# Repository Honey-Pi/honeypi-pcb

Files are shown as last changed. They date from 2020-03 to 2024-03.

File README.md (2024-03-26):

# HoneyPi-PCB Overview

Printed circuit boards (PCB) for the Raspberry Pi to connect various sensors to avoid the use of jumper cables and flying resistors :-).

Three variants are available (0.x, 2.x, 3.x):
## HoneyPi-PCB V0.1 [link](./PCB_V0.1) no further development or maintenance.

## HoneyPi-PCB V2.x [link](./PCB_V2.x) designed for Raspberry Zero, Zero 2. Read the manual first for Raspberry 3 and 4.  
## HoneyPi-PCB V3.x [link](./PCB_V3.x) designed for Raspberry 3, Raspberry 4 and the Zeros.
## Rasperry 5 is not yet supported.
--> HoneyPi-PCB V2.x and V3.x have a different range of functions.  
 
## Sensor extension board HX711 & DS18b20 for HoneyPi-PCB V2.x [link](./PCB_Sensor_Board_2.x_HX711_DS18b20)  

## Sensor extension board BME280/680 for HoneyPi-PCB V2.x [link](./PCB_Sensor_Board_2.x_BME280_680_ATH10_HDC1080)  
## I2C Extender (one set to extend the range) [link](./PCB_I2C_Extender)

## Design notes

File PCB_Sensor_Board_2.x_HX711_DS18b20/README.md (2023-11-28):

# HoneyPi-PCB Sensor Board HX711 and DS18b20

Extension board for the HoneyPi-PCB 2.x.   
Pitch lenght 2.0 mm for Grove plugs or similar.  
Pitch lenght 2.54 mm for (e.g.) terminal blocks as an alternative. 
New: Wago cage clamp block support

Designed to be mounted close to the load cell. To ensure that the analogue voltage signal is subject to the least interference.  
Shielded cable to the load cell and aluminium housing are designed for this purpose.  
1x HX711 (two different types)  
3x DS18b20 (cable/external) + 1x DS18b20 TO-92 (board)  

Feature list and bill of material is still on working. 

## V2.0x circuit diagram [link](./HoneyPI_Platine_2.05_Sensor_Plan.pdf)  
Check out this [blogpost](https://www.honey-pi.de/)  

Status: Under development.  
This version is currently being procured and tested.  
Please do not order these without having contacted us before.  
Thank you for your understanding!   

You can upload this [gerber file](./Sensor_Board_2.05_HX711_DS18b2.zip) to [this manufactory service](https://jlcpcb.com/quote) to get few PCBs. 10 pieces of this board cost about 7 € with delivery.  
(price date 2021)

### Pictures
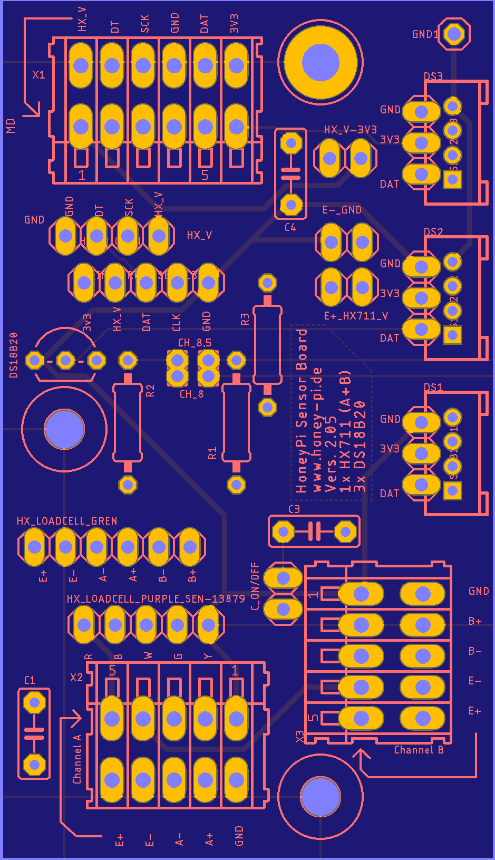
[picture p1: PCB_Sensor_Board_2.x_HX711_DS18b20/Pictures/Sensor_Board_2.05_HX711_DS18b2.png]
Board render picture


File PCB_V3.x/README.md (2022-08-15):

# HoneyPi-PCB 3.0x

Printed circuit board (PCB) for the Raspberry Pi 3 or 4 to connect various sensors.  
Pitch lenght 2.00 mm for Grove plugs or similar.  
Pitch lenght 2.54 mm for terminal blocks as an alternative. 
 
- Three differend possible power supplies possible.  
- 8x HX711 in combination with the PCB_HoneyPI_2.0 Sensor Board HX711_DS18b20  
- 8x DS18b20 + 1x DS18b20 (TO-92 onboard)  
- 8x I2C: BME680, BME280, PCF8591, OLED ...
- incl. interface for the WittyPi (90° connector)
- Space for momentary buttons, resistors, capacitors as well to connect the LED 

Designed for the Raspberry Pi 3 and 4 and also for the Raspberry Pi Zero WH / Zero 2 W   
Feature list and bill of material is still on working.  

## Circuit diagram [link](./HoneyPI_Platine_3.00_Schaltplan.pdf)
## Layout [link](./HoneyPI_Platine_3.00_layout.pdf)
Status: Tested.  

You can upload this [gerber file](./HoneyPI_Platine_3.00_2022-08-15.zip) to [this manufactory service](https://jlcpcb.com/quote) to get few PCBs. 5 pieces of this board cost me about 7 € with delivery. 

### Pictures
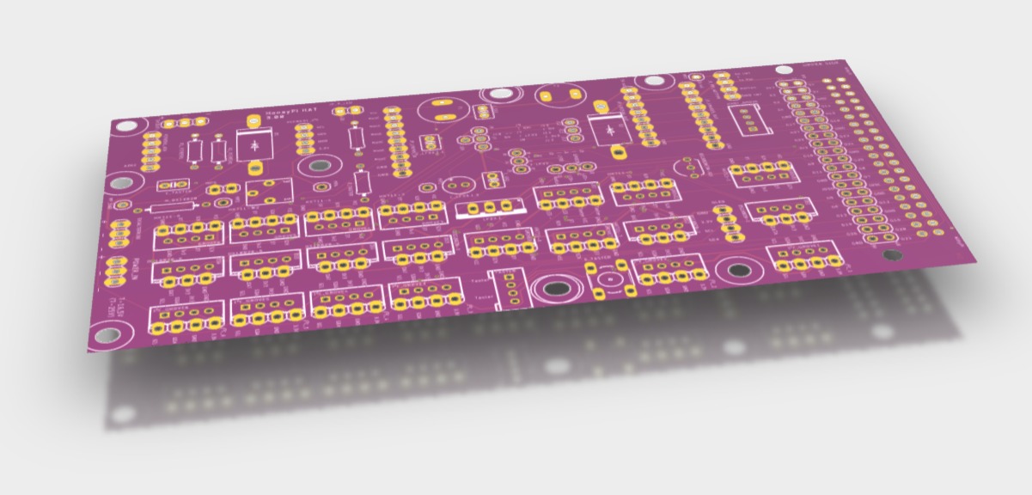
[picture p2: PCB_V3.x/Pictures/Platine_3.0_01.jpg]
Board render picture

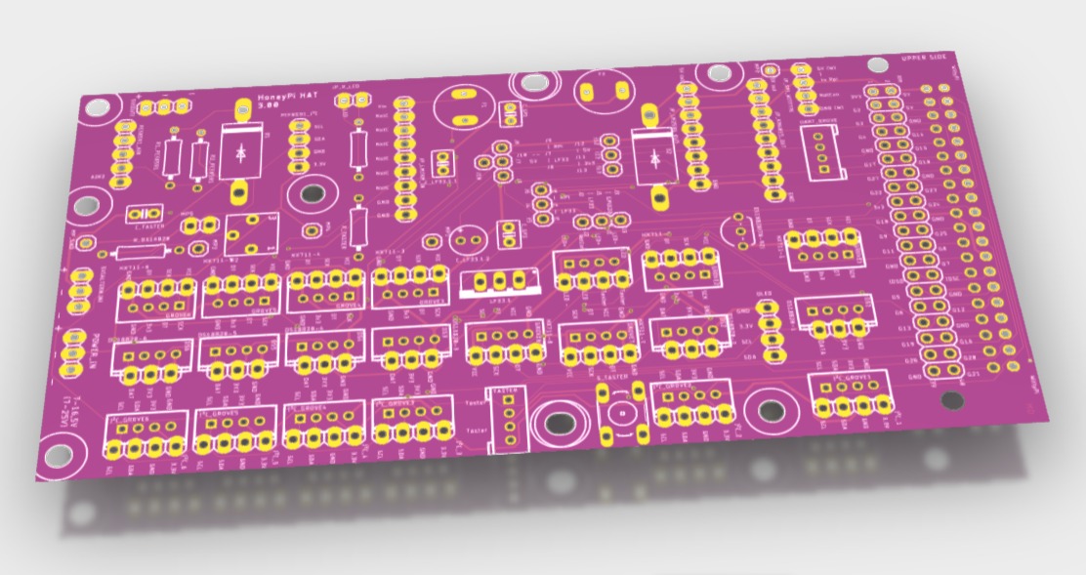
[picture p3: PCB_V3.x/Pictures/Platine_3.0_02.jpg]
Board render picture

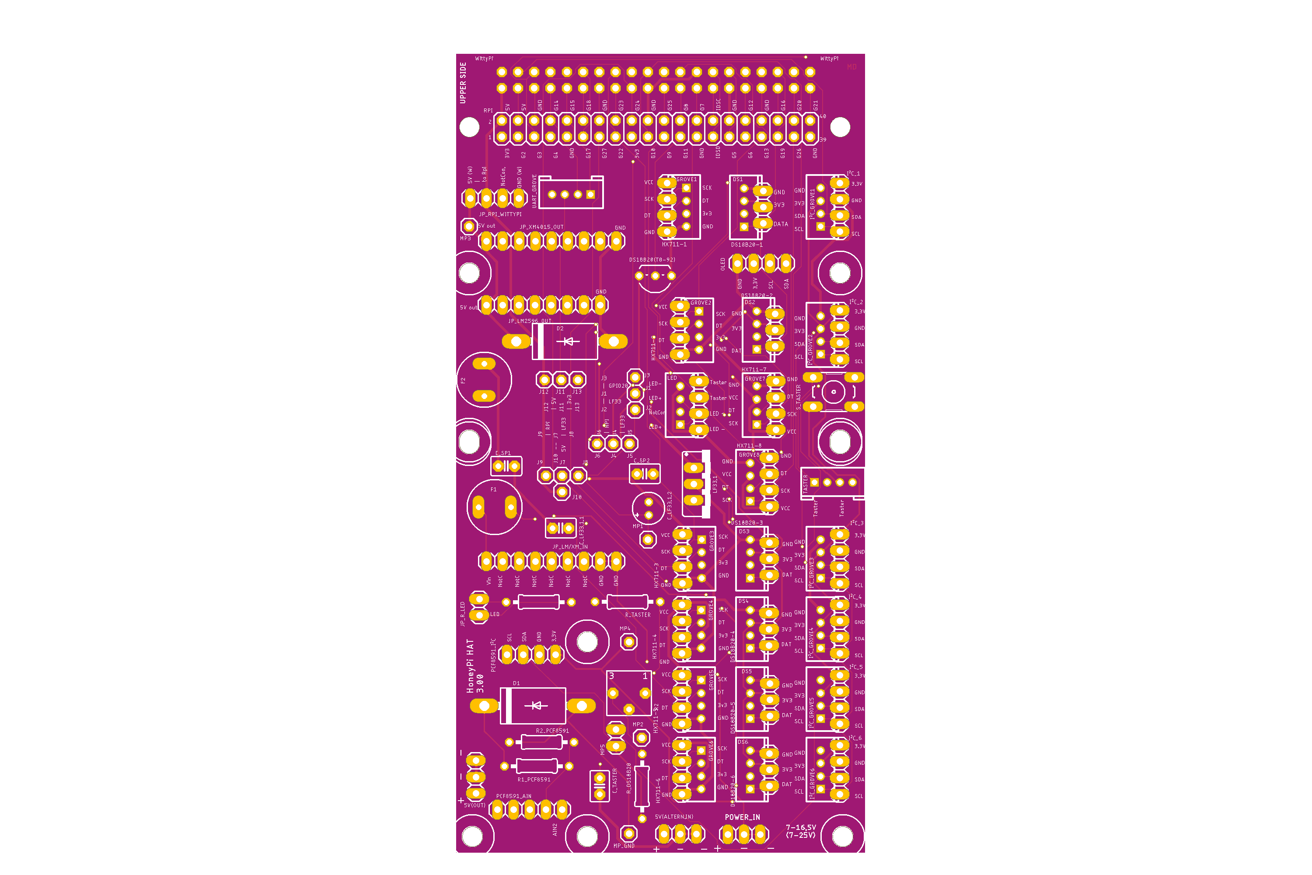
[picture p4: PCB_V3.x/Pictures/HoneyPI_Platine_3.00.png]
Board render picture


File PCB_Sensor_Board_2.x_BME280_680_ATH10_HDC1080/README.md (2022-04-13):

# HoneyPI-PCB Sensor Board 2.x BME280/BME680

Extension board for the HoneyPi-PCB 2.x.  
Pitch lenght 2.0 mm for Grove plugs or similar.  
Pitch lenght 2.54 mm for pins or...  
Designed to be mounted in a separate housing that allows humidity to be measured.  
1x BME680 or BME280 or 1x ATH10 or 1x HDC1080 or 1x sht31
--> We adapt these sensors because of the fixed i2c adresses. 

Feature list and bill of material is still on working.   

## V2.0x circuit diagram [link](./PCB_Sensor_Board_2.x_BME280_680_ATH10_HDC1080.pdf)
Check out this [blogpost](https://www.honey-pi.de/)

Status: Under development.  
This version is currently being procured and tested.  
Please do not order these without having contacted us before.  
Thank you for your understanding!  

You can upload this [gerber file](./PCB_Sensor_Board_2.x_BME280_680_ATH10_HDC1080.zip) to [this manufactory service](https://jlcpcb.com/quote) to get few PCBs. 10 pieces of this board cost about 7 € with delivery. 

### Pictures
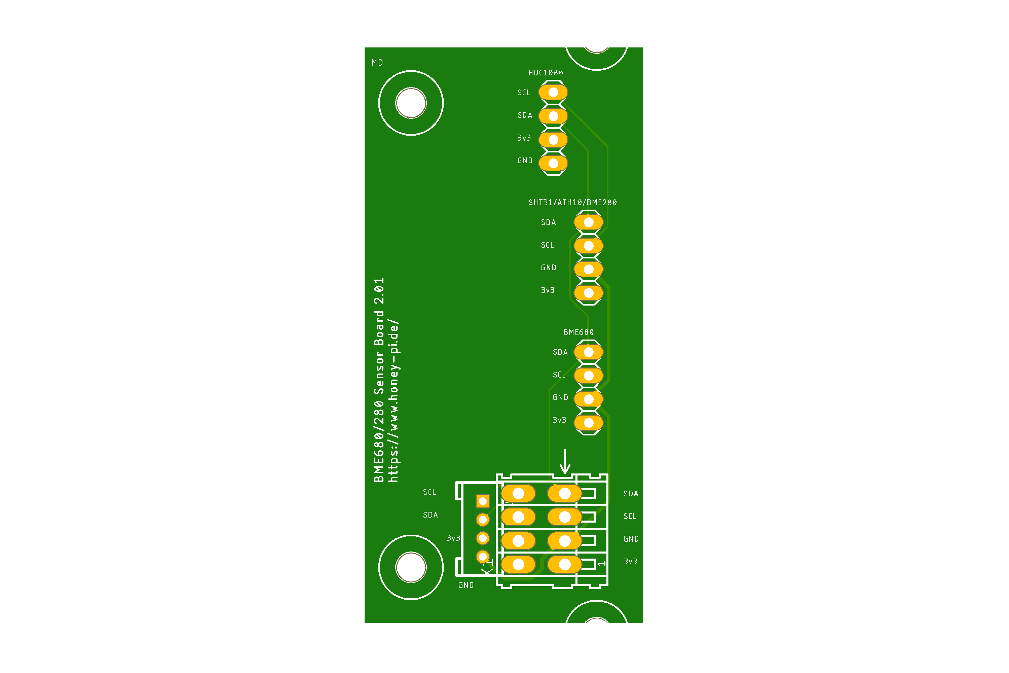
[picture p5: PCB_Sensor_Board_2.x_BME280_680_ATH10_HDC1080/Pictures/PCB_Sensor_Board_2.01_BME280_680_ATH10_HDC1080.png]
Board render picture


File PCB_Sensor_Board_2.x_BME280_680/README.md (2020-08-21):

# HoneyPI-PCB Sensor Board 2.x BME280/BME680

Extension board for the HoneyPi-PCB 2.x.  
Pitch lenght 2.0 mm for Grove plugs or similar.  
Pitch lenght 2.54 mm for pins or...  
Designed to be mounted in a separate housing that allows humidity to be measured.  
1x BME680 (or BME280)  
2x I²C   
...we are am thinking about a sunlight sensor or.

Feature list and bill of material is still on working.   

## V2.0 BETA circuit diagram [link](./HoneyPI_Platine_2.0_BME680_280_Sensor_Board_21-8-2020.pdf)
Check out this [blogpost](https://www.honey-pi.de/)

Status: Under development.  
This version is currently being procured and tested.  
Please do not order these without having contacted us before.  
Thank you for your understanding!  

You can upload this [gerber file](./HoneyPI_Platine_2.0_BME680_280_Sensor_Board_2020-08-21.zip) to [this manufactory service](https://jlcpcb.com/quote) to get few PCBs. 10 pieces of this board cost about 7 € with delivery. 

### Pictures
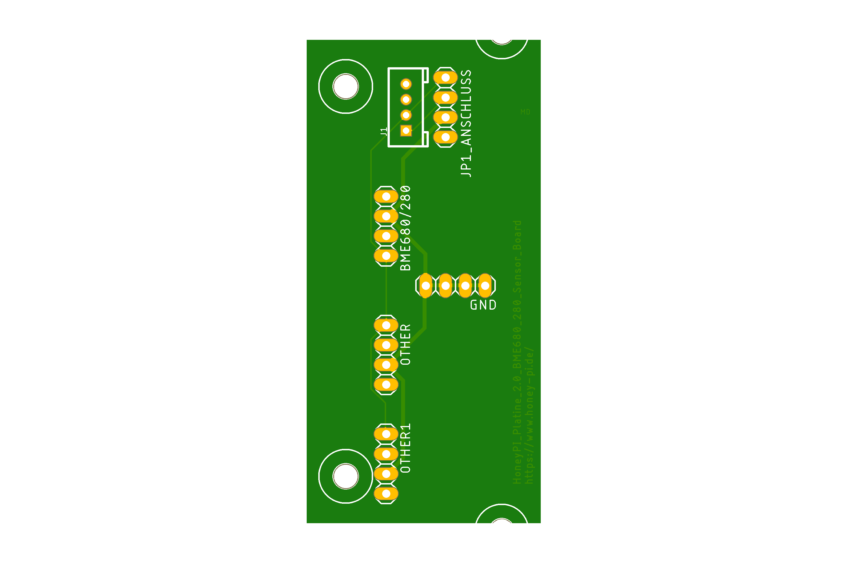
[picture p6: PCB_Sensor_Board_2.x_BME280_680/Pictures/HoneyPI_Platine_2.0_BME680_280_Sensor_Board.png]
Board render picture


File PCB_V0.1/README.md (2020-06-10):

# honeypi-pcb V0.1

Printed circuit board (PCB) for the Raspberry Pi to connect various sensors. To avoid the use of jumper cables.

## V0.1 [link](./PCB_V0.1)
Check out this [blogpost](https://www.honey-pi.de/teil-3-adapter-lk-fuer-grove-stecker/) about the grove connector board for the Raspberry Zero.
You can upload the [gerber file](./Grove%20Base%20HAT%20For%20Raspberry%20Pi%20Zero_2019-01-13.zip) to [this manufactory service](https://jlcpcb.com/quote). 10 pieces of this board cost about 7 € with delivery. 

### Pictures
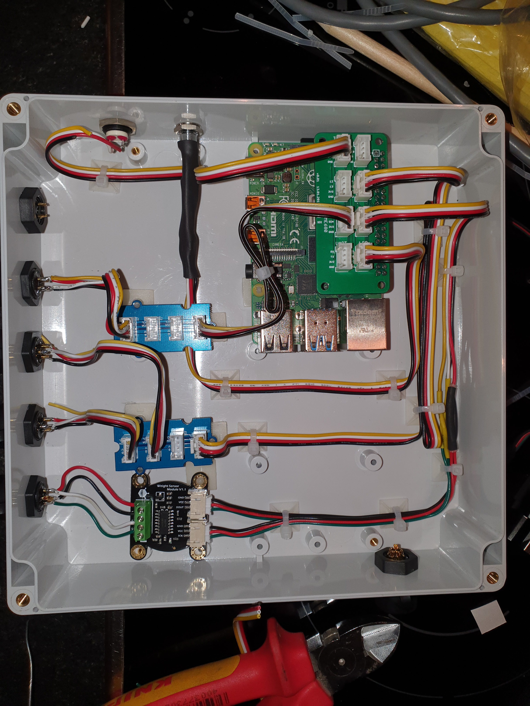
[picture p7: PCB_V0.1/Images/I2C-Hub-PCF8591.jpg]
RPi 4 with Board

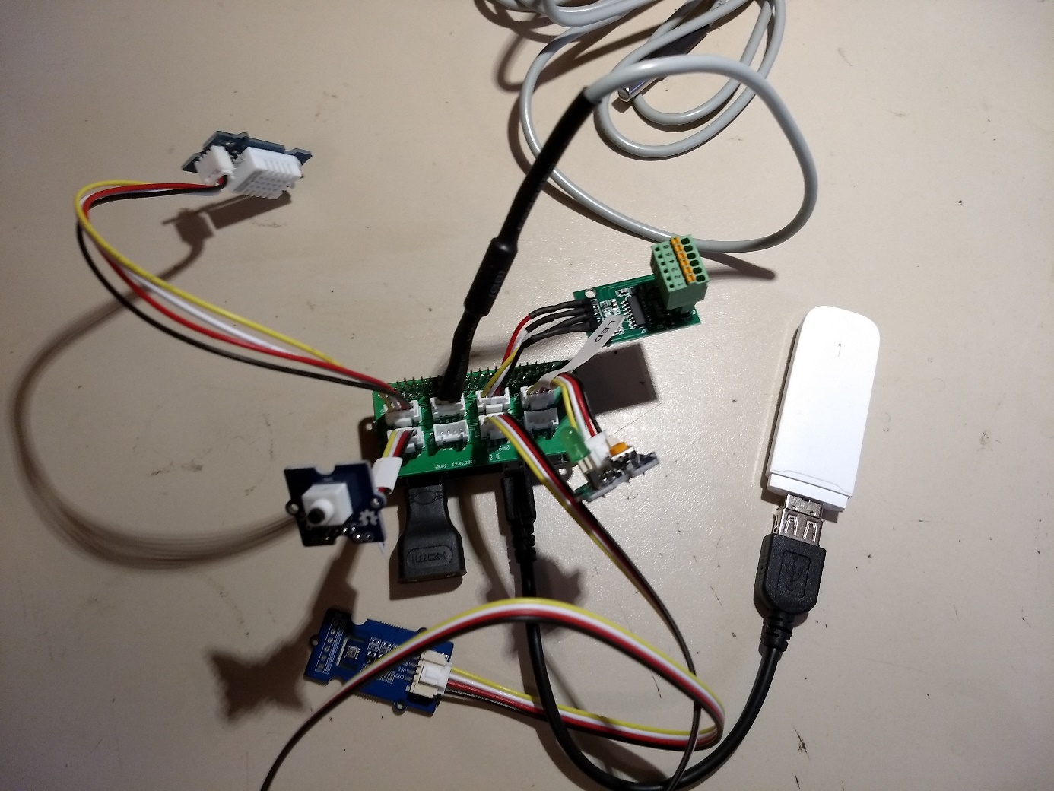
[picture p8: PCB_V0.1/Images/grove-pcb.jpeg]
RPi Zero with Board

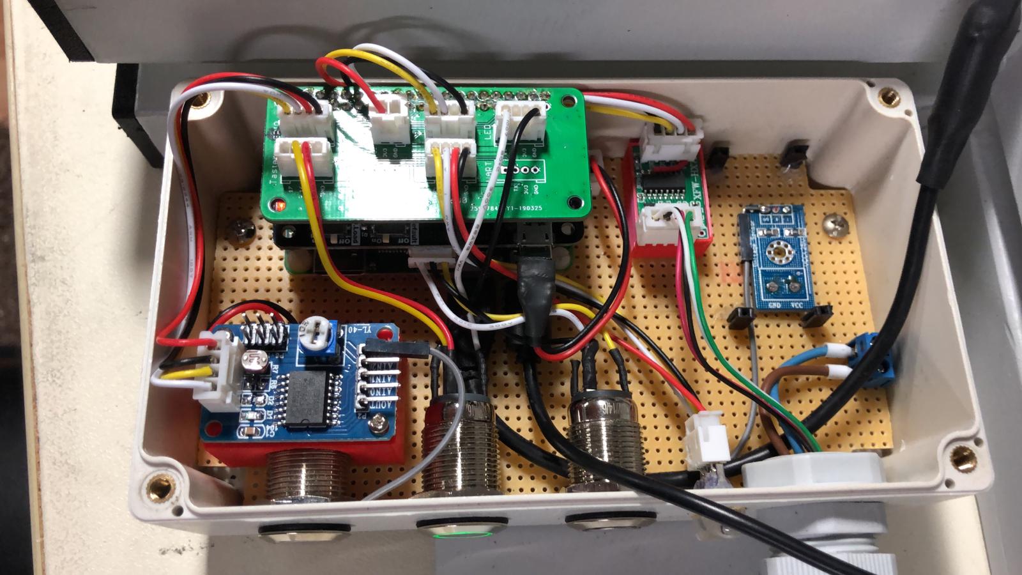
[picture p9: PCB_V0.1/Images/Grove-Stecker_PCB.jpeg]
RPi Zero WittyPi + PCB Board


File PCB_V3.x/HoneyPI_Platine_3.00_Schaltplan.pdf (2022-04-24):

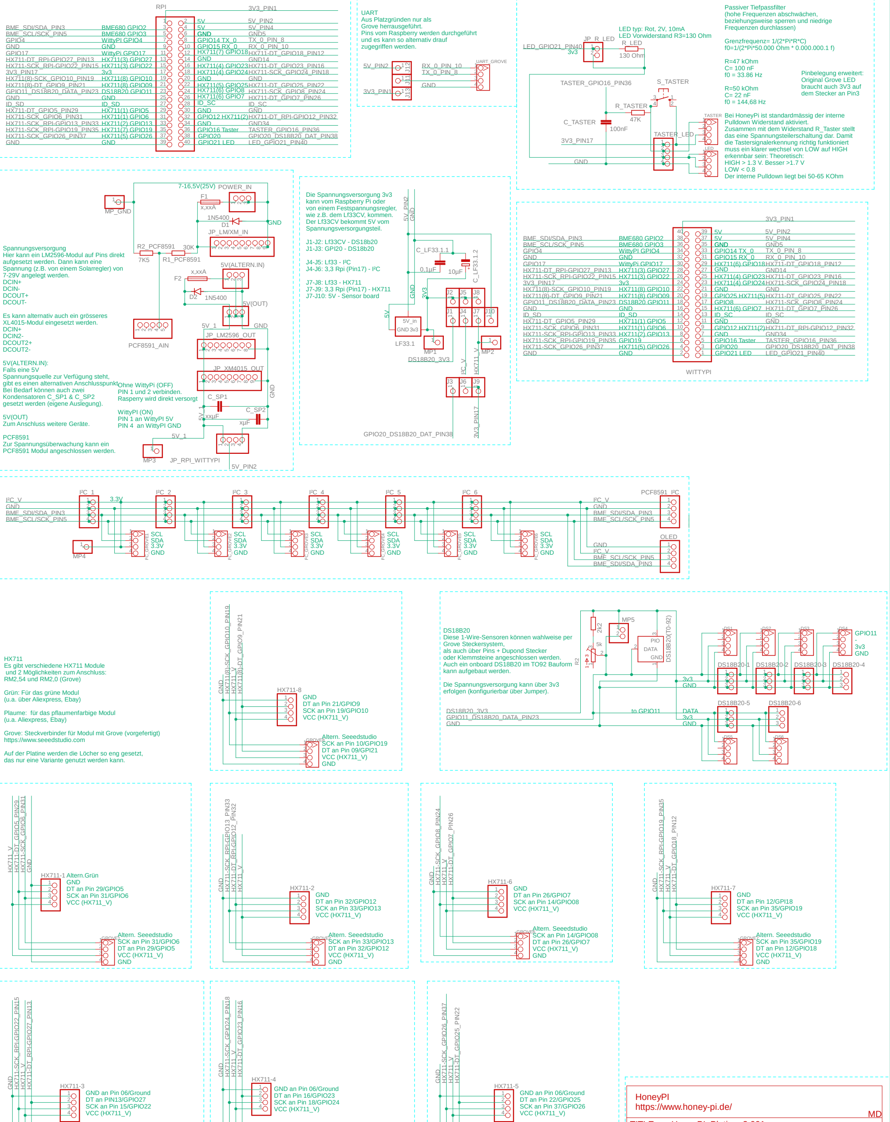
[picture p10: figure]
SpiceOrder 2; SpiceOrder 1; SpiceOrder 1 xxµF; xµF; 130 Ohm 2k2; x,xxA; RPI; 4 TASTER_LED; R_LED; 3 POWER_IN; PIO; GND; DATA 2; DS¹⁸B²⁰⁽T0⁻92⁾; 3 5V(OUT); R2_PCF8591; R1_PCF8591; LED; 4TASTER; C_TASTER; R_TASTER; 4GROVE1; 4GROVE2; 4 I²C_GROVE¹; HX711(4) GPIO24; TX_0_PIN_8 2; 4UART_GROVE; 4 PCF8591_I²C; 4 2 S_TASTER; I²C_2; I²C_1; JP_RPI_WITTYPI; 5V(ALTERN.IN); 5V_in GND 3v3; JP_R_LED; JP_XM4015_OUT; JP_LM2596_OUT; 4 OLED; 4 I²C_GROVE²; 4GROVE6; I²C_3; 4 I²C_GROVE³; I²C_4; 4 I²C_GROVE⁴; I²C_5; 4 I²C_GROVE⁵; I²C_6; 4 I²C_GROVE⁶; 40 39 WITTYPI; 4GROVE7; 4GROVE8; 1 MP_GND; HX711(4) GPIO23; 5 PCF8591_AIN; HX711-DT_GPIO5_PIN29; BME_SCL/SCK_PIN5; BME_SCL/SCK_PIN5 HX⁷¹¹_V; HX⁷¹¹_V HX⁷¹¹_V HX⁷¹¹_V; HX⁷¹¹_V; HX⁷¹¹_V HX⁷¹¹_V; HX711-DT_RPI-GPIO12_PIN32; LED_GPIO21_PIN40; TASTER_GPIO16_PIN36; TASTER_GPIO16_PIN36 HX⁷¹¹⁻SCK_RPI-GPIO¹³_PIN³³; HX711-SCK_RPI-GPIO13_PIN33; HX711-DT_RPI-GPIO27_PIN13 HX⁷¹¹⁻SCK_RPI-GPIO²²_PIN¹⁵; HX711-SCK_RPI-GPIO22_PIN15; HX711-DT_GPIO23_PIN16 HX711-SCK_GPIO24_PIN18; HX711-SCK_GPIO6_PIN31; HX711-DT_GPIO25_PIN22 HX⁷¹¹⁻SCK_GPIO²⁶_PIN³⁷; HX711-SCK_GPIO26_PIN37; TX_0_PIN_8; RX_0_PIN_10; BME_SDI/SDA_PIN3; 3V3_PIN17; 3V3_PIN17 3V³_PIN¹⁷; 3V3_PIN1; I²C_V; I²C_V I²C_V ⁵V_PIN²; 5V_PIN2; GPIO11_DS18B20_DATA_PIN23; GPIO11_DS18B20_DATA_PIN23 ⁵V_1; HX711-SCK_GPIO8_PIN24; HX711-SCK_GPIO8_PIN24 HX⁷¹¹⁻SCK_GPIO⁸_PIN²⁴ HX711-DT_GPIO7_PIN26; HX711(8)-SCK_GPIO10_PIN19; HX711(8)-SCK_GPIO10_PIN19 HX⁷¹¹⁽⁸⁾⁻SCK_GPIO¹⁰_PIN¹⁹; HX711-DT_GPIO18_PIN12; GPIO20_DS18B20_DAT_PIN38; GPIO20_DS18B20_DAT_PIN38 GND GND; GND GND; GND GND GND; GND GND GND GND GND; GND GND GND GND; GPIO4; GPIO4 GPIO17; GPIO17; 5V_PIN4; GND5; GND14; GND34; HX711-SCK_RPI-GPIO19_PIN35; HX⁷¹¹⁻SCK_RPI-GPIO¹⁹_PIN³⁵; HX711(8)-DT_GPIO9_PIN21; HoneyPI; https://www.honey-pi.de/; 3v3 DATA GND; 3v3 GND; HX711(7) GPIO18; Altern.Grün GND; BME680 GPIO2 BME680 GPIO3 WittyPI GPIO4; WittyPi GPIO17 GND; HX711(1) GPIO6; 5VGPIO12 HX711(2); GPIO11; -3v3 GND; to GPIO11; HX711(5) GPIO25; HX711(5) GPIO26; GND GPIO15 RX_0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

# HX711-DT_GPIO5_PIN29 HX⁷¹¹⁻DT_GPIO⁵_PIN²⁹

# HX711-DT_RPI-GPIO12_PIN32 HX⁷¹¹⁻DT_RPI-GPIO¹²_PIN³²

# HX711-DT_RPI-GPIO27_PIN13 HX⁷¹¹⁻DT_RPI-GPIO²⁷_PIN¹³

# HX711-DT_GPIO23_PIN16 HX⁷¹¹⁻DT_GPIO²³_PIN¹⁶

# HX711-SCK_GPIO24_PIN18 HX⁷¹¹⁻SCK_GPIO²⁴_PIN¹⁸

# HX711-SCK_GPIO6_PIN31 HX⁷¹¹⁻SCK_GPIO⁶_PIN³¹

HX711-DT_GPIO25_PIN22 | HX⁷¹¹⁻DT_GPIO²⁵_PIN²²
HX711-DT_GPIO7_PIN26 | HX⁷¹¹⁻DT_GPIO⁷_PIN²⁶

# HX711-DT_GPIO18_PIN12 HX⁷¹¹⁻DT_GPIO¹⁸_PIN¹²

# HX711(8)-DT_GPIO9_PIN21 HX⁷¹¹⁽⁸⁾⁻DT_GPIO⁹_PIN²¹

DT an Pin 29/GPIO5 SCK an Pin 31/GPIO6 VCC (HX711_V)

HX711(8) GPIO09 DS18B20 GPIO11 HX711(1) GPIO5

HX711(2) GPIO13 GND GND | GND GPIO16 Taster GPIO21 LED GND GND GND GND
Altern. Seeedstudio SCK an Pin 31/GPIO6 DT an Pin 29/GPIO5 VCC (HX711_V) GND | GND
DT an Pin 32/GPIO12 SCK an Pin 33/GPIO13 VCC (HX711_V) Altern. Seeedstudio SCK an Pin 33/GPIO13 DT an Pin 32/GPIO12 VCC (HX711_V) GND GND an Pin 06/Ground DT an PIN13/GPIO27 SCK an Pin 15/GPIO22 VCC (HX711_V) Altern. Seeedstudio SCK an Pin 15/GPIO22 DT an PIN13/GPIO27 VCC (HX711_V) GND | GND an Pin 06/Ground DT an Pin 16/GPIO23 SCK an Pin 18/GPIO24 VCC (HX711_V) | Altern. Seeedstudio SCK an Pin 18/GPIO24 DT an Pin 16/GPIO23 VCC (HX711_V) GND | GND an Pin 06/Ground DT an Pin 22/GPIO25 SCK an Pin 37/GPIO26 VCC (HX711_V) Altern. Seeedstudio SCK an Pin 37/GPIO26 DT an Pin 22/GPIO25 VCC (HX711_V) GND

Grove: Steckverbinder für Modul mit Grove (vorgefertigt)

Auf der Platine werden die Löcher so eng gesetzt,

das nur eine Variante genutzt werden kann. | DS18B20 Diese 1-Wire-Sensoren können wahlweise per

oder Klemmsteine angeschlossen werden. Auch ein onboard DS18B20 im TO92 Bauform

Pins vom Raspberry werden durchgeführt und es kann so alternativ drauf zugegriffen werden.

Spannungsversorgung Hier kann ein LM2596-Modul auf Pins direkt aufgesetzt werden. Dann kann eine

Spannung (z.B. von einem Solarregler) von 7-29V angelegt werden. DCIN+ DCIN- DCOUT+ DCOUT- Es kann alternativ auch ein grösseres

XL4015-Modul eingesetzt werden. DCIN+ DCIN2- DCOUT2+ DCOUT2- 5V(ALTERN.IN): Falls eine 5V

gibt es einen alternativen Anschlusspunkt. Bei Bedarf können auch zwei Kondensatoren C_SP1 & C_SP2

5V(OUT) Zum Anschluss weitere Geräte. PCF8591 Zur Spannungsüberwachung kann ein

wie z.B. dem Lf33CV, kommen. Der Lf33CV bekommt 5V vom f0=1/(2*Pi*50.000 Ohm * 0.000.000.1 f) R=47 kOhm C= 100 nF

Bei HoneyPi ist standardmässig der interne Pulldown Widerstand aktiviert. Zusammen mit dem Widerstand R_Taster stellt

die Tastersignalerkennung richtig funktioniert muss ein klarer wechsel von LOW auf HIGH erkennbar sein: Theoretisch: HIGH > 1.3 V. Besser >1.7 V

LOW < 0.8 Der interne Pulldown liegt bei 50-65 KOhm

A

B

C

D

E

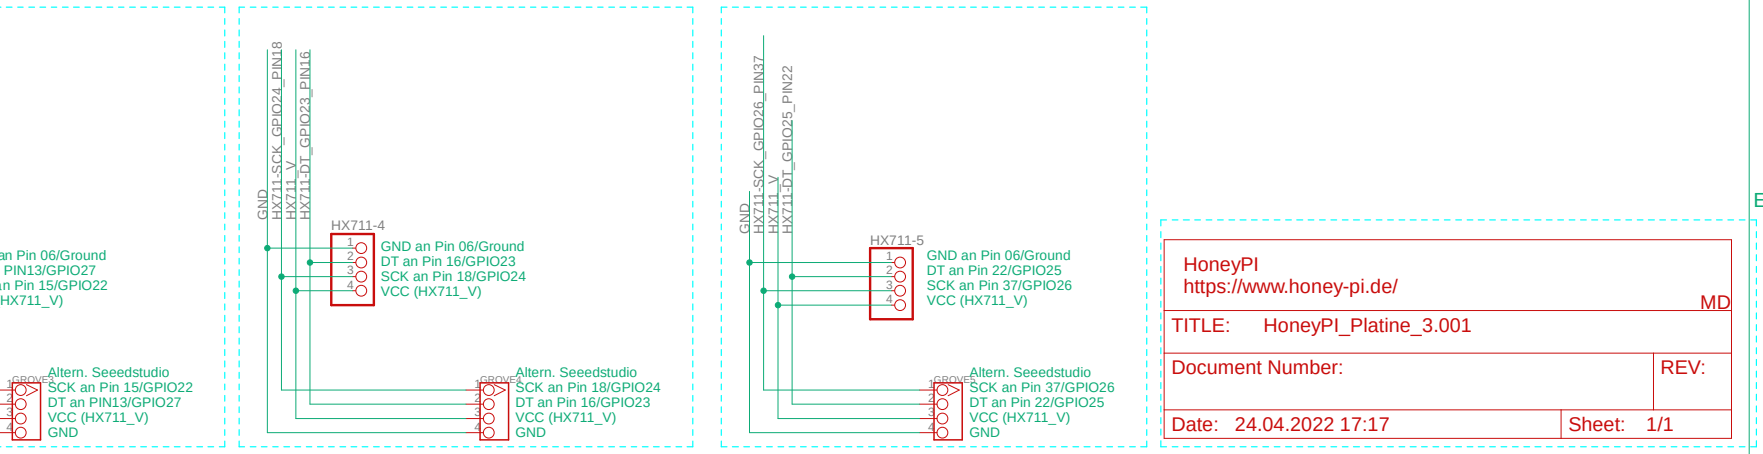
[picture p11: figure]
4GROVE3; 4GROVE4; 4GROVE5; Date:; Sheet:; REV:; TITLE:; Document Number:; HoneyPI_Platine_3.001

1 | 2 | 3 | 4 | 5 | 6 | 7 | 8

A

B

C

D

E

1 | 2 | 3 | 4 | 5 | 6 | 7 | 8

Ohne WittyPi (OFF) PIN 1 und 2 verbinden. Rasperry wird direkt versorgt

DT an Pin 26/GPIO7 SCK an Pin 14/GPIO08 VCC (HX711_V) Altern. Seeedstudio SCK an Pin 14/GPIO08 DT an Pin 26/GPIO7 VCC (HX711_V) GND

5VHX711(6) GPIO18 BME680 GPIO2 BME680 GPIO3 WittyPI GPIO4

HX711(8) GPIO09 DS18B20 GPIO11 HX711(1) GPIO5

HX711(2) GPIO13 GND | GND GPIO16 Taster GPIO21 LED GND GND GND GND

DT an Pin 12/GPI18 SCK an Pin 35/GPIO19 VCC (HX711_V) Altern. Seeedstudio SCK an Pin 35/GPIO19 DT an Pin 12/GPIO18 VCC (HX711_V) GND

DT an Pin 21/GPIO9 SCK an Pin 19/GPIO10 VCC (HX711_V) Altern. Seeedstudio SCK an Pin 10/GPIO19 DT an Pin 09/GPI21 VCC (HX711_V) GND

Original Grove LED braucht auch 3V3 auf dem Stecker an Pin3 HX711(8) GPIO10 GND

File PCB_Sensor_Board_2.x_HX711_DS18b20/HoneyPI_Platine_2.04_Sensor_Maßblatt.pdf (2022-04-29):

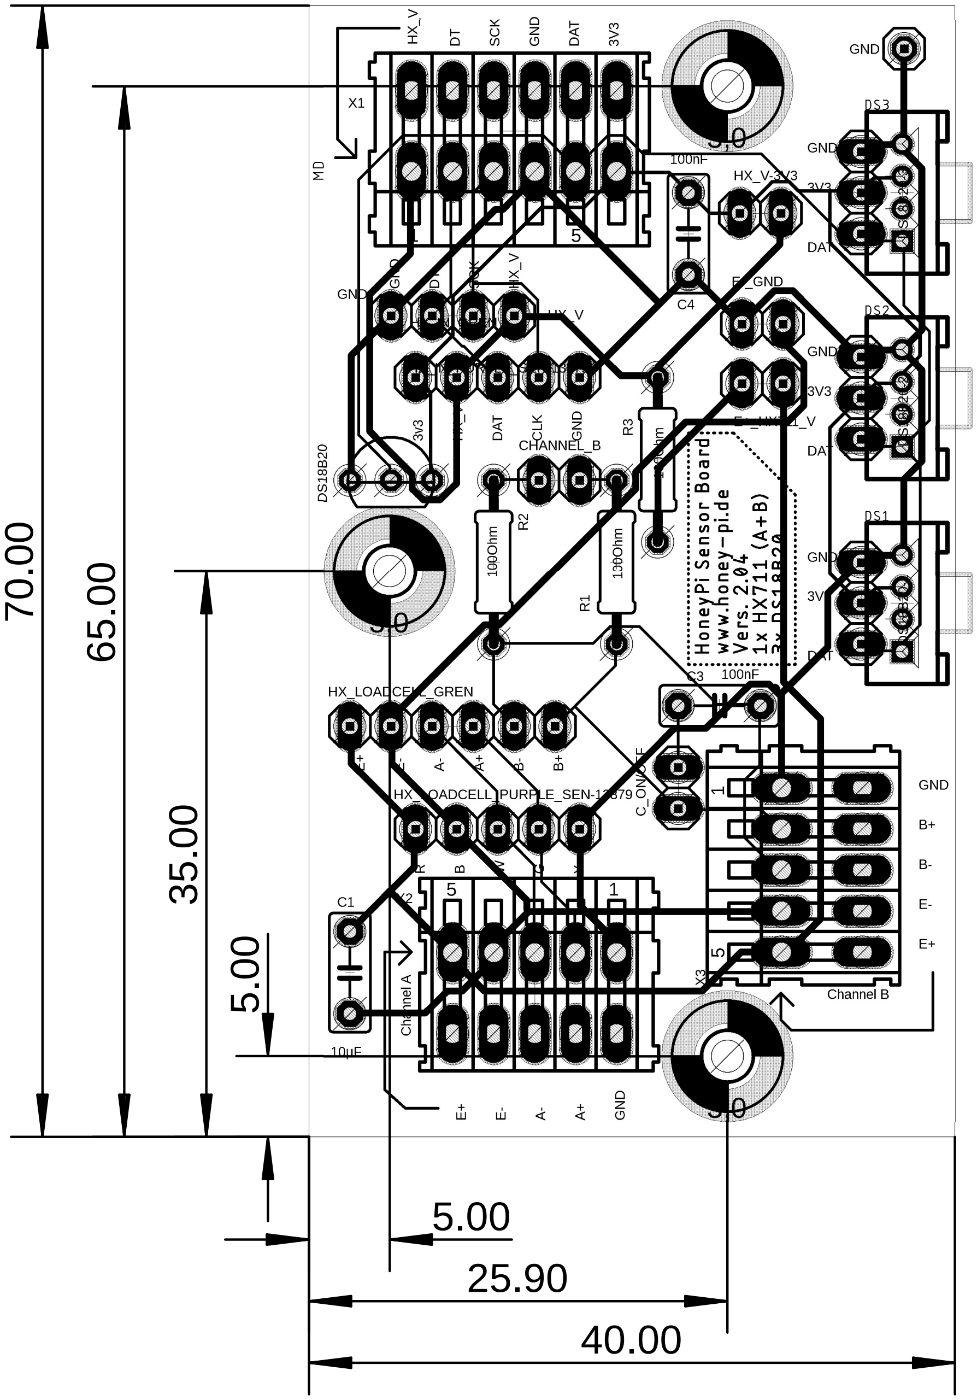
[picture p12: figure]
25.90 DS¹⁸B²⁰

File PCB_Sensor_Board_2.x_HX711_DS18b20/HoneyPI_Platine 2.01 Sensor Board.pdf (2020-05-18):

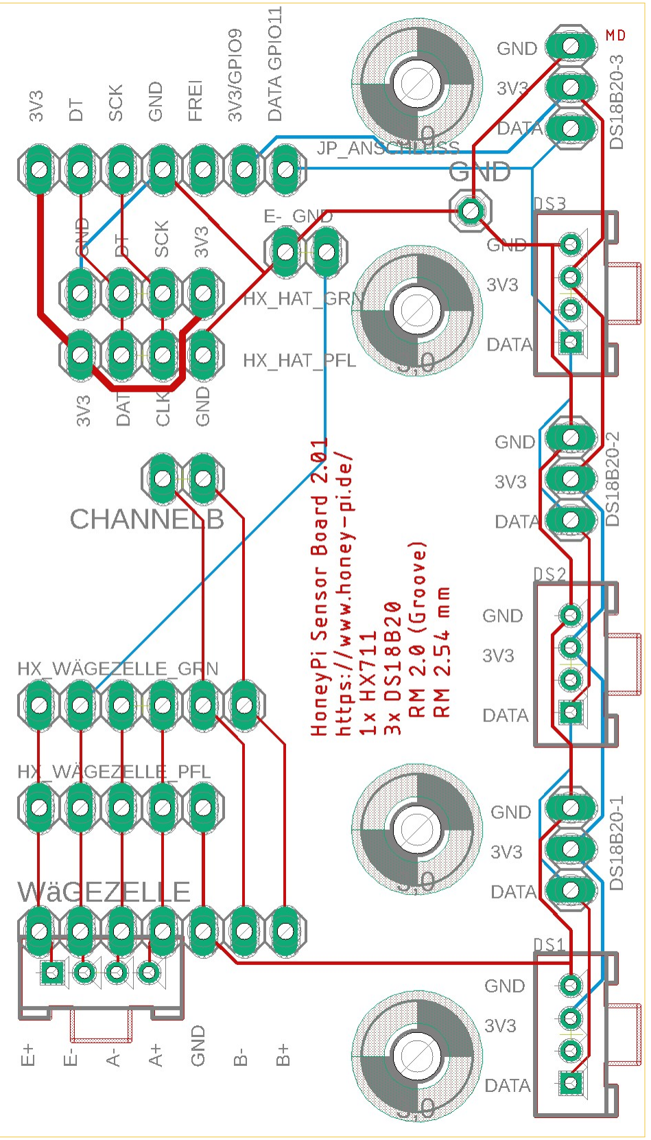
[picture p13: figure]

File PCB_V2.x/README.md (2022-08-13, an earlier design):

# HoneyPi-PCB 2.0x

Printed circuit board (PCB) for the Raspberry Pi ZERO to connect various sensors.  
Pitch lenght 2.x mm for Grove plugs or similar.  
Pitch lenght 2.54 mm for terminal blocks as an alternative. 
 
- Three differend possible power supplies possible.  

- 5x HX711...  

- 8x DS18b20 + 1x DS18b20 (TO-92 onboard)  

- 2x BME680 / BME280 

- 1x I²C interface (instead of second BME)

- 1x PCF8591

- incl. interface for the WittyPi / Timer Board

Designed for the Raspian Zero and NOT for Raspian Pi 1 to 4  
Feature list and bill of material is still on working.  
## You can find some helpfull instructions (only in German at the moment ) [here](./Bienenwaage_Platine_2.x_D2.07.pdf)

## V2.0x circuit diagram [link](./Schaltplan_2.021-13-8-2022.pdf)
Check out this [blogpost](https://honey-pi.de/neue-platine-v2-fuer-raspberry-zero/) for the Raspberry Zero.

Status: Tested, working.  
This version has been tested and found to be good and released.

You can upload this [gerber file](./HoneyPI_Platine_2.021_2022-08-13.zip) to [this manufactory service](https://jlcpcb.com/quote) to get few PCBs. 5 pieces of this board cost me about 7 € with delivery. 

### Pictures
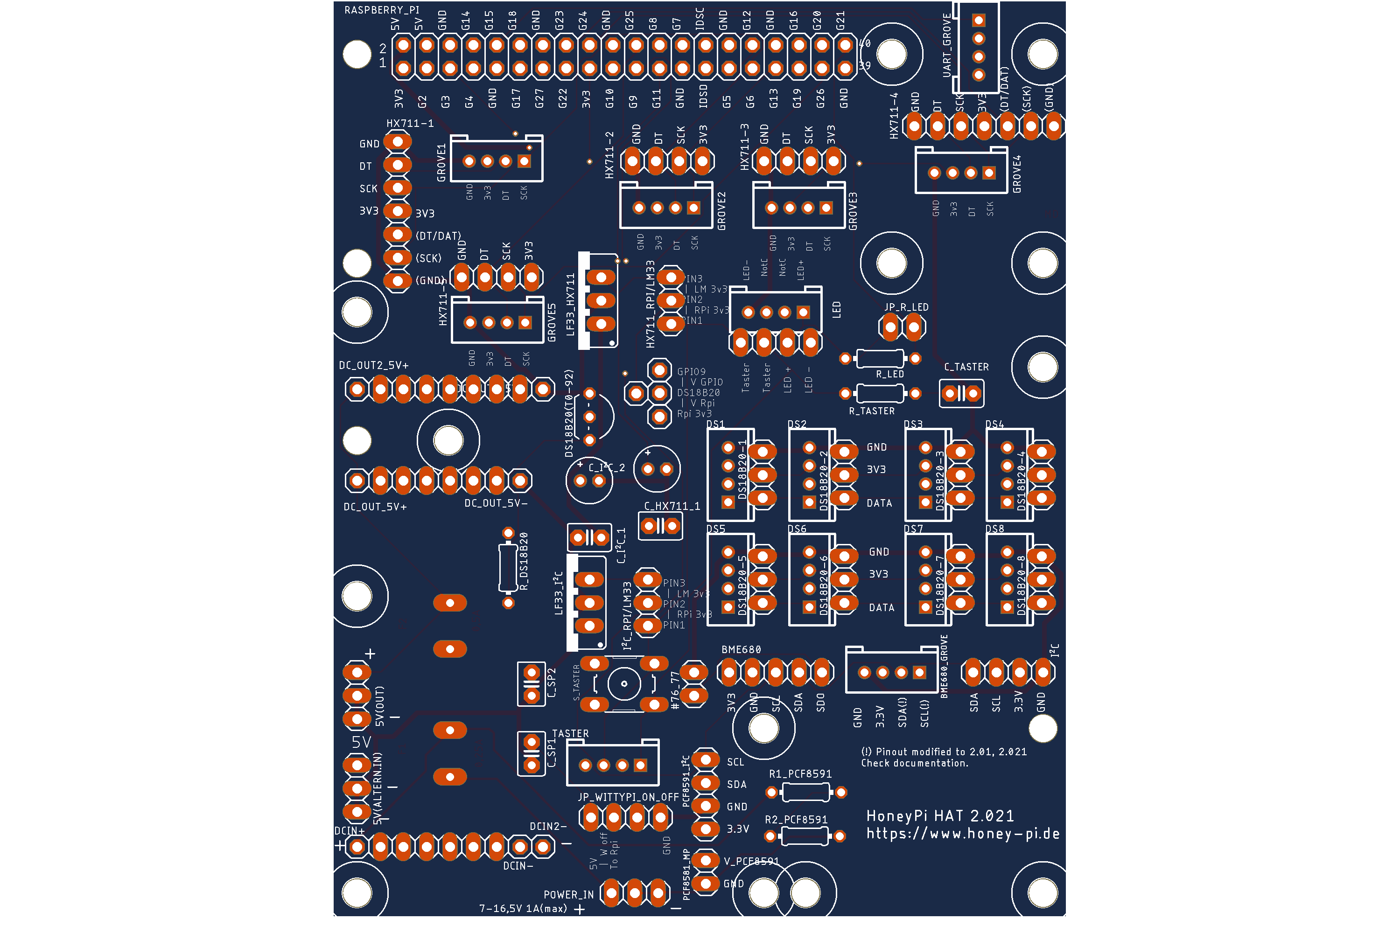
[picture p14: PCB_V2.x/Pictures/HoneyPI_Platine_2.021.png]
Board render picture


Users of the board version 2.01: Please use the schematic 2.01.1 [link](./OLD/Schaltplan_2.01.1-21.01.2021.pdf)

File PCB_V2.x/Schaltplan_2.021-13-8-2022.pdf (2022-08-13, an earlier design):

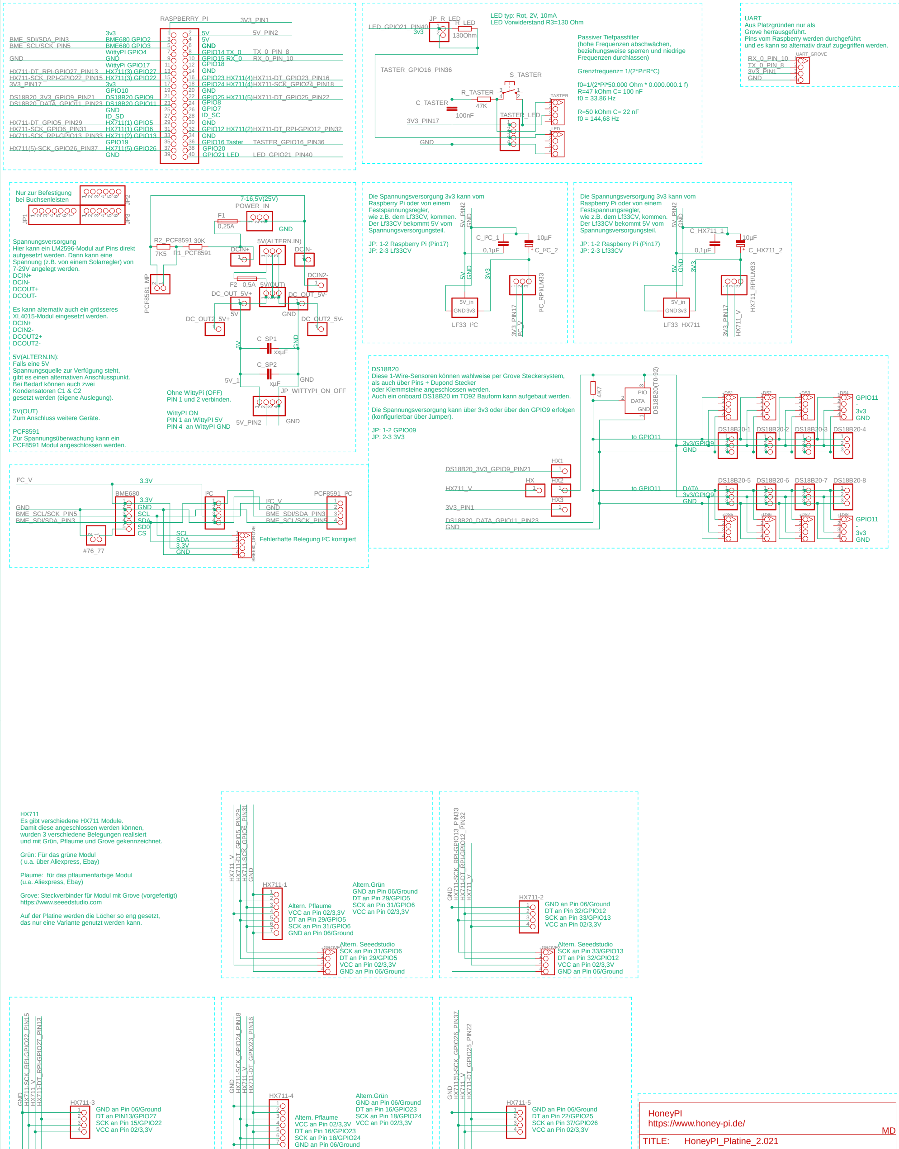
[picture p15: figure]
xxµF; xµF; 130Ohm; GND; RASPBERRY_PI; 4 TASTER_LED; R_LED; 1 DCIN+; 1 DCIN- 1 DC_OUT_5V+; 1 DC_OUT_5V- ¹; 3 POWER_IN; PIO; DATA 2; DS¹⁸B²⁰⁽T0⁻92⁾; 5V(OUT); R2_PCF8591; R1_PCF8591; LED; 4TASTER; C_TASTER; R_TASTER; 4GROVE1; 4GROVE2; 4 BME⁶⁸⁰_GROVE; 4UART_GROVE; 4 PCF8591_I²C; 3 I²C_RPI/LM33; C_I²C_1; 1 DC_OUT2_5V+; 1 DCIN2- 1 DC_OUT2_5V-; 4 2 S_TASTER; 1 PCF8581_MP; I²C; 5 BME680; 3 HX711_RPI/LM33; JP_WITTYPI_ON_OFF; 5V(ALTERN.IN); 5V_in GND 3v3; LF33_I²C; 5V_in GND3v3; C_I²C_2; JP_R_LED; BME_SCL/SCK_PIN5; BME_SCL/SCK_PIN5 HX⁷¹¹_V; HX⁷¹¹_V; HX⁷¹¹_V HX⁷¹¹_V; DS18B20_3V3_GPIO9_PIN21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

1
2
3

4GROVE3

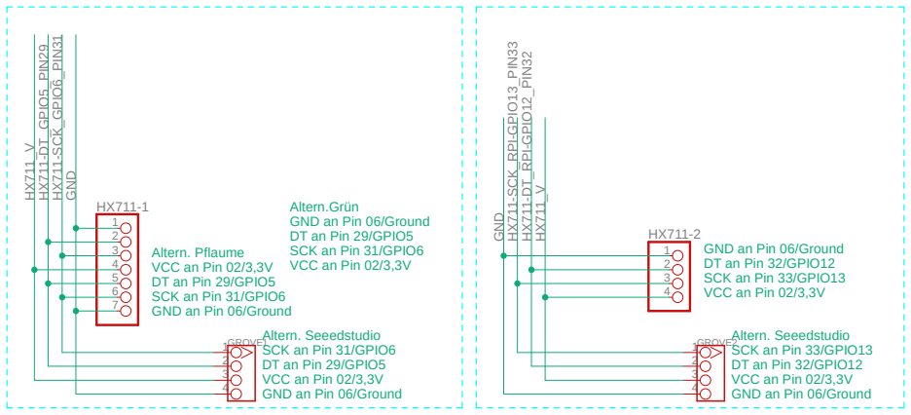
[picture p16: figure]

1
2
3
4GROVE4 | 1
2
3

4GROVE5

HX711-DT_GPIO5_PIN29 | HX⁷¹¹⁻DT_GPIO⁵_PIN²⁹
HX711-DT_RPI-GPIO12_PIN32 | HX⁷¹¹⁻DT_RPI-GPIO¹²_PIN³²

# TASTER_GPIO16_PIN36 HX⁷¹¹⁻SCK_RPI-GPIO¹³_PIN³³

HX711-DT_RPI-GPIO27_PIN13 HX⁷¹¹⁻SCK_RPI-GPIO²²_PIN¹⁵ | HX⁷¹¹⁻DT_RPI-GPIO²⁷_PIN¹³
HX711-SCK_RPI-GPIO22_PIN15 | HX711-DT_GPIO23_PIN16 HX⁷¹¹⁻DT_GPIO²³_PIN¹⁶

# HX711-SCK_GPIO24_PIN18 HX⁷¹¹⁻SCK_GPIO²⁴_PIN¹⁸

HX711-SCK_GPIO6_PIN31 | HX⁷¹¹⁻SCK_GPIO⁶_PIN³¹
HX711-DT_GPIO25_PIN22 | HX⁷¹¹⁽⁵⁾⁻SCK_GPIO²⁶_PIN³⁷ | HX⁷¹¹⁻DT_GPIO²⁵_PIN²²
Date: | Sheet:

## REV:

## Document Number:

12.08.2022 15:54 | 1/1

Altern. Pflaume VCC an Pin 02/3,3V DT an Pin 29/GPIO5 SCK an Pin 31/GPIO6 GND an Pin 06/Ground

Altern.Grün GND an Pin 06/Ground DT an Pin 29/GPIO5 SCK an Pin 31/GPIO6 VCC an Pin 02/3,3V

DS18B20 GPIO9 DS18B20 GPIO11 HX711(1) GPIO5

HX711(2) GPIO13 GND GND | GND GPIO16 Taster GPIO21 LED GND GND GND GND
Altern. Seeedstudio SCK an Pin 31/GPIO6 DT an Pin 29/GPIO5 VCC an Pin 02/3,3V GND an Pin 06/Ground | GND an Pin 06/Ground DT an Pin 32/GPIO12 SCK an Pin 33/GPIO13 VCC an Pin 02/3,3V

Altern. Seeedstudio SCK an Pin 33/GPIO13 DT an Pin 32/GPIO12 VCC an Pin 02/3,3V GND an Pin 06/Ground GND an Pin 06/Ground DT an PIN13/GPIO27 SCK an Pin 15/GPIO22 VCC an Pin 02/3,3V

Altern. Seeedstudio SCK an Pin 15/GPIO22 DT an PIN13/GPIO27 VCC an Pin 02/3,3V GND an Pin 06/Ground | Altern. Pflaume VCC an Pin 02/3,3V DT an Pin 16/GPIO23 SCK an Pin 18/GPIO24 GND an Pin 06/GroundAltern.Grün GND an Pin 06/Ground DT an Pin 16/GPIO23 SCK an Pin 18/GPIO24 VCC an Pin 02/3,3V
Altern. Seeedstudio SCK an Pin 18/GPIO24 DT an Pin 16/GPIO23 VCC an Pin 02/3,3V GND an Pin 06/Ground | GND an Pin 06/Ground DT an Pin 22/GPIO25 SCK an Pin 37/GPIO26 VCC an Pin 02/3,3V

Altern. Seeedstudio SCK an Pin 37/GPIO26 DT an Pin 22/GPIO25 VCC an Pin 02/3,3V GND an Pin 06/Ground

HX711 Es gibt verschiedene HX711 Module.

und mit Grün, Pflaume und Grove gekennzeichnet.

Grove: Steckverbinder für Modul mit Grove (vorgefertigt)

Auf der Platine werden die Löcher so eng gesetzt,
das nur eine Variante genutzt werden kann.

DS18B20 Diese 1-Wire-Sensoren können wahlweise per Grove Steckersystem,

Auch ein onboard DS18B20 im TO92 Bauform kann aufgebaut werden.

Die Spannungsversorgung kann über 3v3 oder über den GPIO9 erfolgen (konfigurierbar über Jumper). JP: 1-2 GPIO09

und es kann so alternativ drauf zugegriffen werden.

Spannungsversorgung Hier kann ein LM2596-Modul auf Pins direkt aufgesetzt werden. Dann kann eine

Spannung (z.B. von einem Solarregler) von 7-29V angelegt werden. DCIN+ DCIN- DCOUT+ DCOUT- Es kann alternativ auch ein grösseres

XL4015-Modul eingesetzt werden. DCIN+ DCIN2- DCOUT2+ DCOUT2- 5V(ALTERN.IN): Falls eine 5V

gibt es einen alternativen Anschlusspunkt. Bei Bedarf können auch zwei Kondensatoren C1 & C2

5V(OUT) Zum Anschluss weitere Geräte. PCF8591 Zur Spannungsüberwachung kann ein

wie z.B. dem Lf33CV, kommen. Der Lf33CV bekommt 5V vom

JP: 1-2 Raspberry Pi (Pin17) JP: 2-3 Lf33CV f0=1/(2*Pi*50.000 Ohm * 0.000.000.1 f) R=47 kOhm C= 100 nF

wie z.B. dem Lf33CV, kommen. Der Lf33CV bekommt 5V vom

JP: 1-2 Raspberry Pi (Pin17) JP: 2-3 Lf33CV

A

B

C

D

E

1 | 2 | 3 | 4 | 5 | 6 | 7 | 8

A

B

C

D

E

1 | 2 | 3 | 4 | 5 | 6 | 7 | 8

Ohne WittyPi (OFF) PIN 1 und 2 verbinden. WittyPI ON

Fehlerhafte Belegung I²C korrigiert SCL SDA

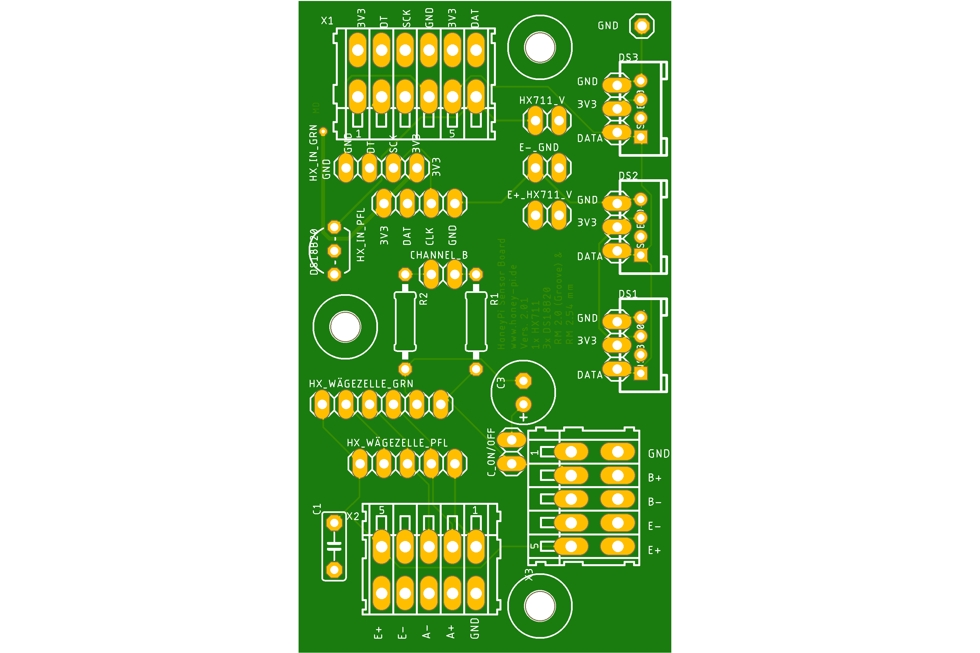
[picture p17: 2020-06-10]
PCB_Sensor_Board_2.x_HX711_DS18b20/Pictures/Sensor_Board_2.01_HX711_DS18b2.png

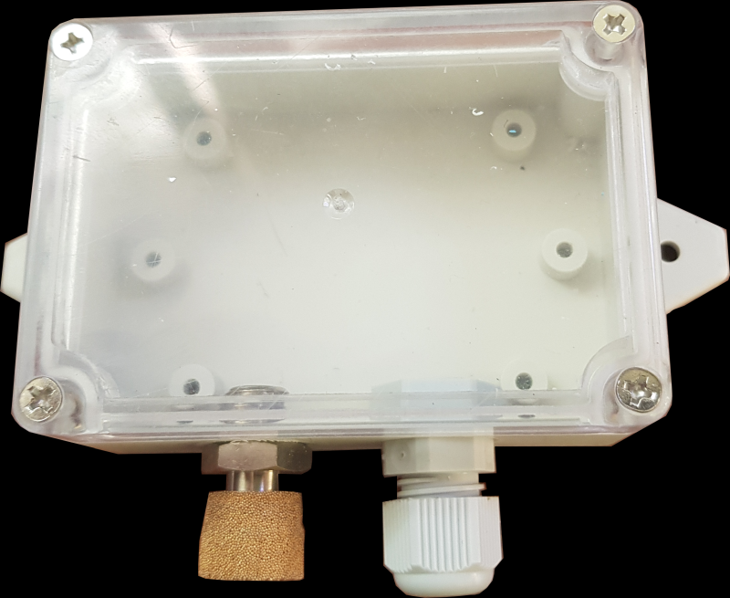
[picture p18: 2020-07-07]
PCB_Sensor_Board_2.x_BME280_680_ATH10_HDC1080/Pictures/Gehäuse mit Belüftung_x800.png

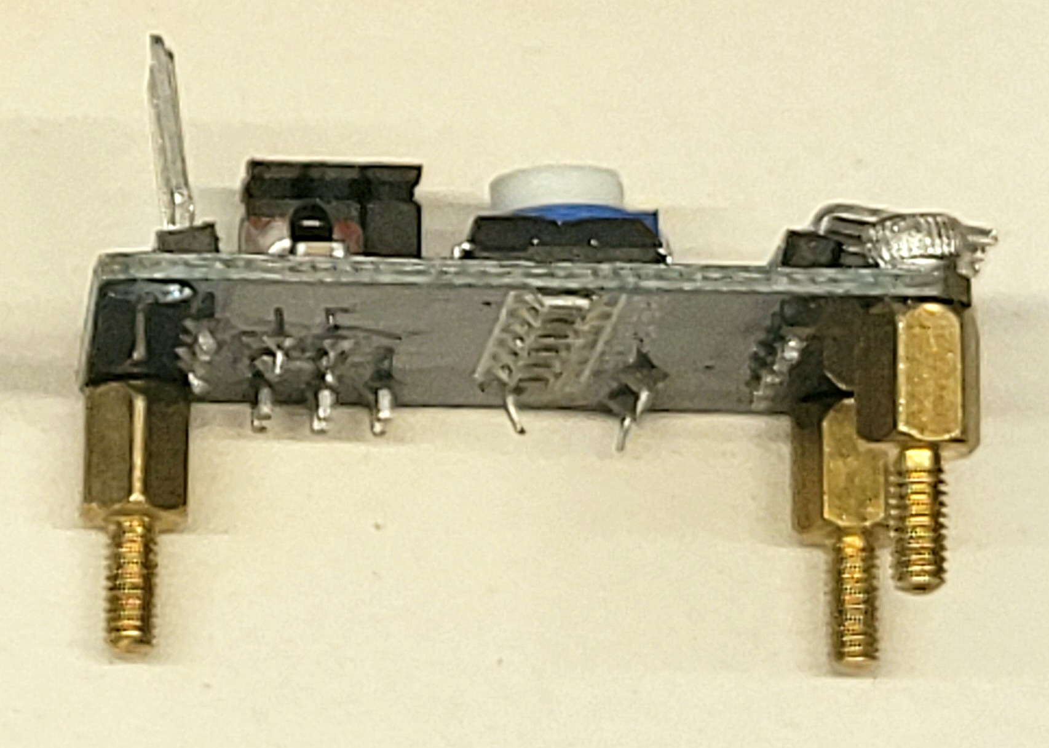
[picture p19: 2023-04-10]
PCB_V3.x/Pictures/PCF8591.jpg

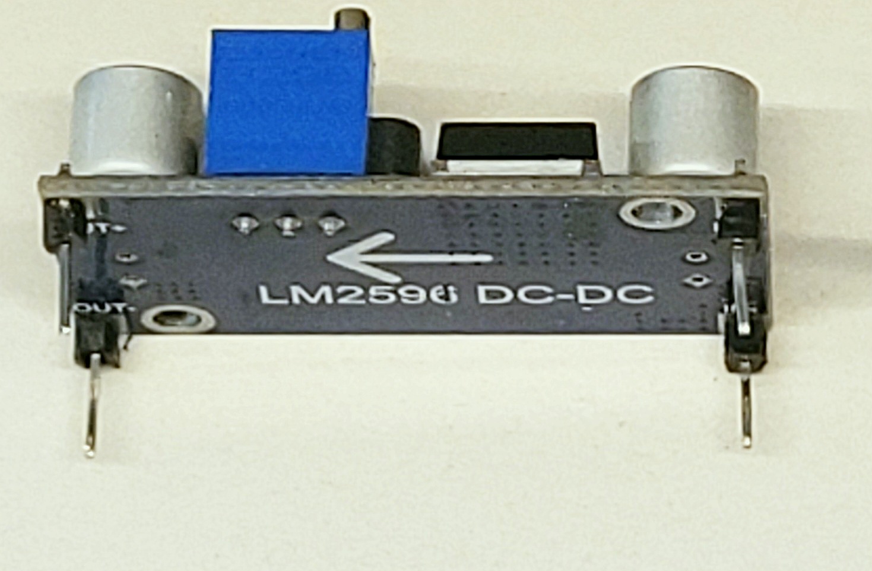
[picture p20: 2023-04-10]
PCB_V3.x/Pictures/LM2596_1.jpg

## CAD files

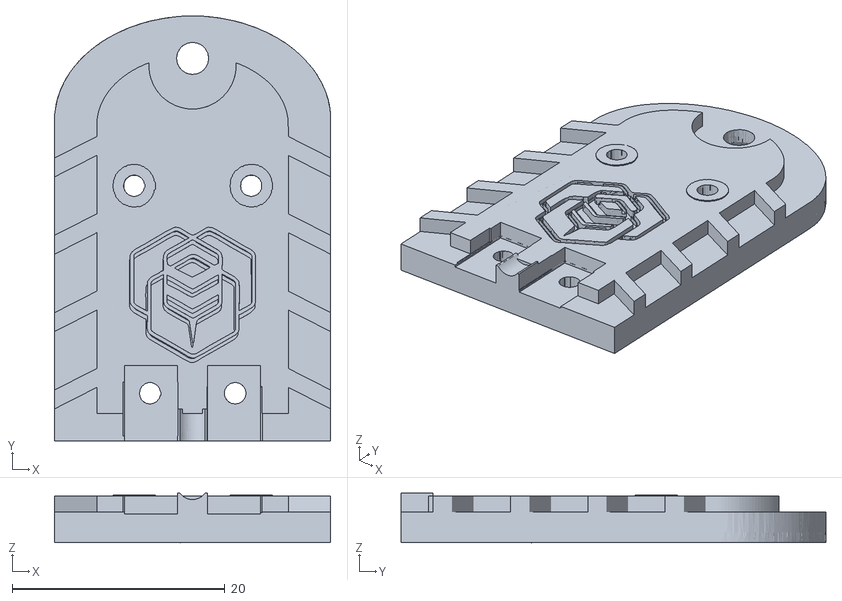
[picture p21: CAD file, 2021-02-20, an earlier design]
PCB_V2.x/Sensor case/Sensor_housing_cover_countersunk_head.stl
26.0 x 40.0 x 4.66

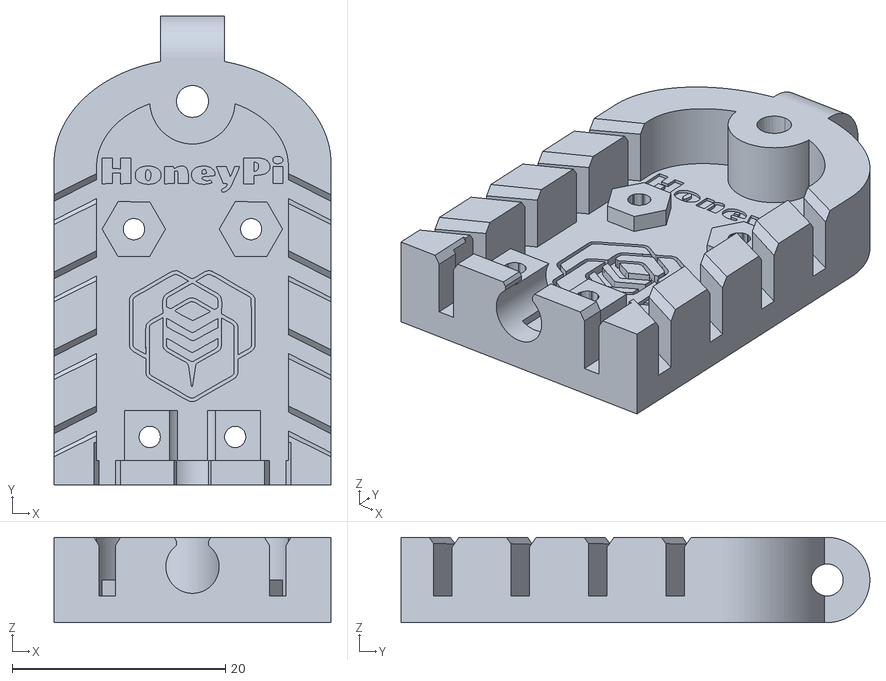
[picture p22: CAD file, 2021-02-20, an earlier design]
PCB_V2.x/Sensor case/Sensor_housing.stl
26.0 x 44.0 x 8.00

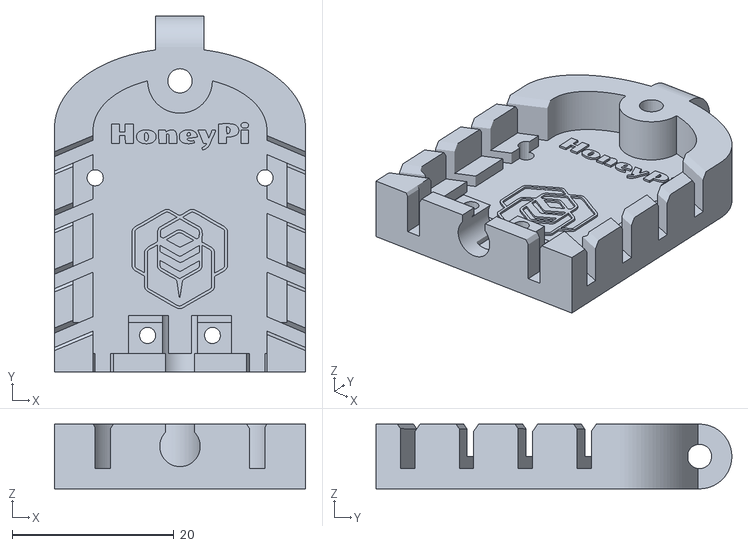
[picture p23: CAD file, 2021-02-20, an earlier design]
PCB_V2.x/Sensor case/Sensorgehäuse_BlueDot_BME680_Gehäuse.stl
31.0 x 44.0 x 8.00

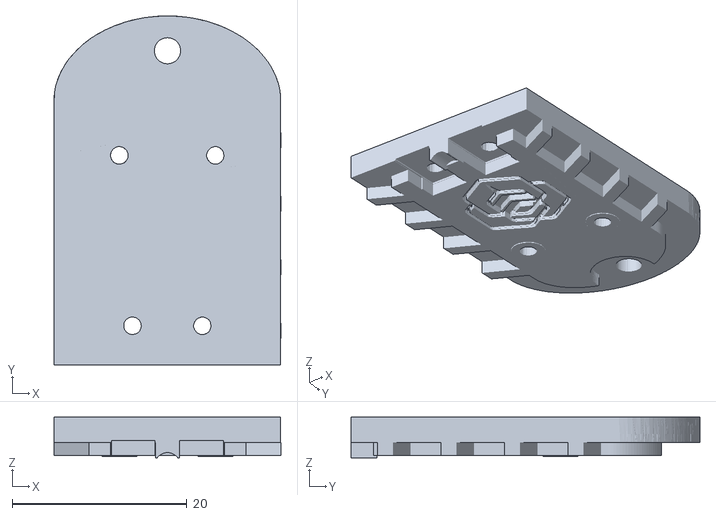
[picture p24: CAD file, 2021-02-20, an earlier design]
PCB_V2.x/Sensor case/Sensor_housing_cover.stl
26.0 x 40.0 x 4.64

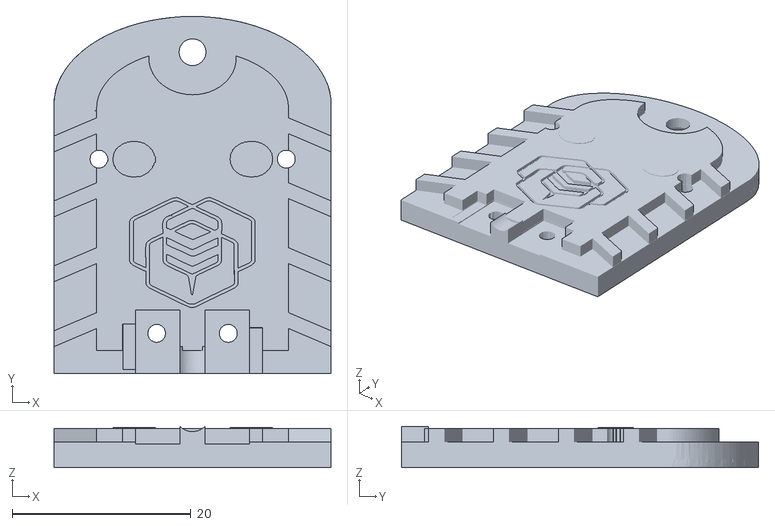
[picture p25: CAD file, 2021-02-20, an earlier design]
PCB_V2.x/Sensor case/Sensorgehäuse_BlueDot_BME680_Deckel.stl
31.0 x 40.0 x 4.64

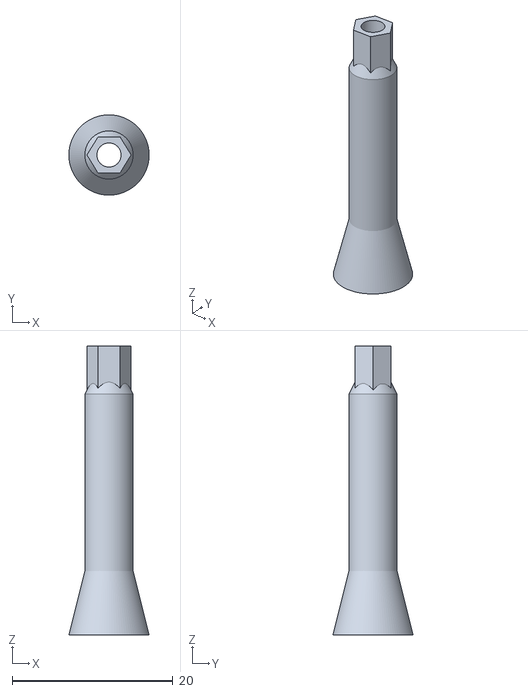
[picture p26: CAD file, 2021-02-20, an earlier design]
PCB_V2.x/Stud bolt/Stehbolzen zum Kleben_36.0 mm.stl
10.0 x 10.0 x 36.0

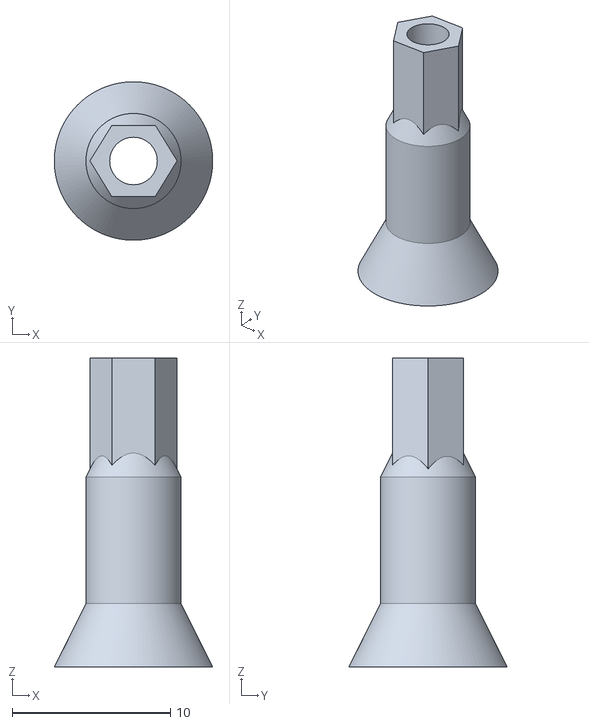
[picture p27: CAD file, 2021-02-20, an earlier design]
PCB_V2.x/Stud bolt/Stehbolzen zum Kleben_19.5 mm.stl
10.0 x 10.0 x 19.5

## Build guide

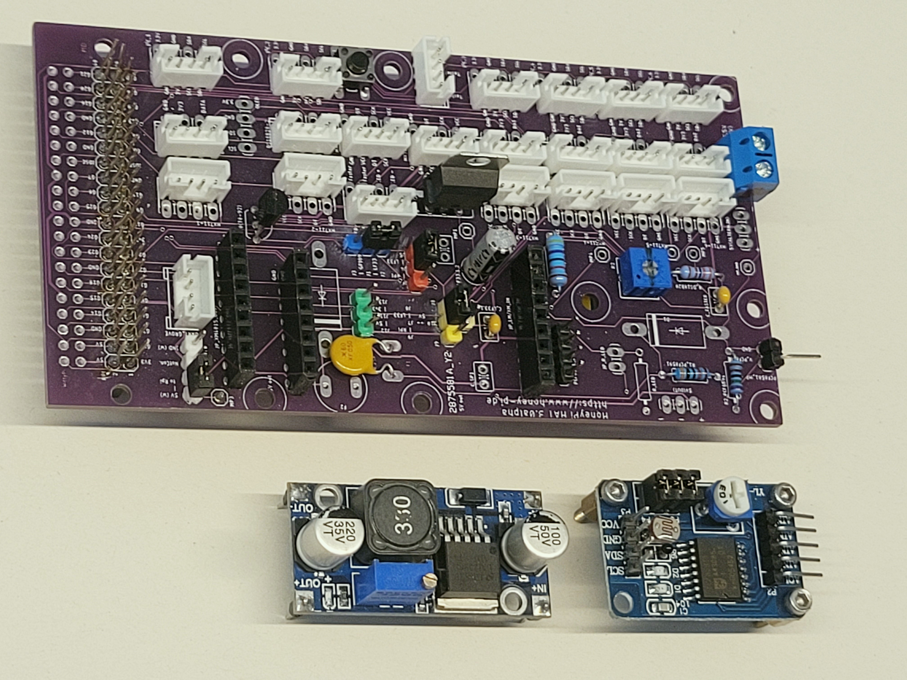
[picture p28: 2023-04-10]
PCB_V3.x/Pictures/V3.x_alpha_ Aufbau 1.jpg

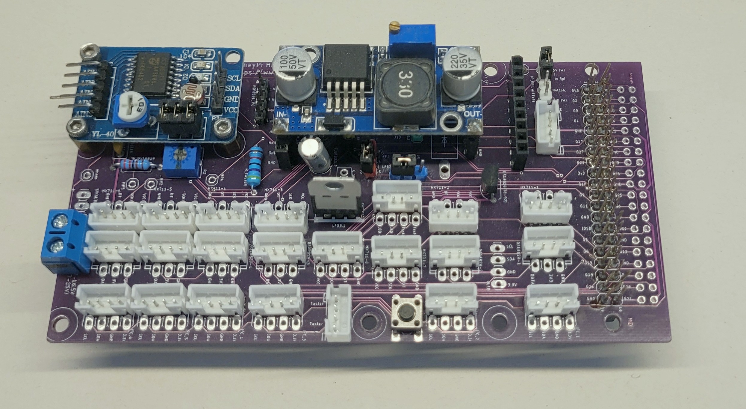
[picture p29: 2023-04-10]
PCB_V3.x/Pictures/V3.x_alpha_ Aufbau 2.jpg

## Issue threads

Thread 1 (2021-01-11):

Support / Kein Taster/keine Temperatur - Minimallayout

JoeRu, 2021-01-11:
Hi,
ich weiß nicht ob das der "richtige" Weg f. eine Support-Anfrage ist - wenn nicht - einfach das Ticket schließen:

Ich bräuchte mal  etwas support; Ich habe im Dezember einen Set Platinen bestellt und versuche gerade ein minimal-Layout (Groove-Taster und Temp-Sensor) und bekomme aber keine Daten vom Taster und den Temperatur-Sensoren (Strom ist da);

[Hier ein Photo vom aktuellen Zustand](https://photos.app.goo.gl/vddKfQMpS9r4rim36)

Ich bin nicht ganz sicher - welche Bauteile noch minimal "da" sein müssen - damit Taster und Sensor funktionieren.
Kontakt gern auch per Messenger.
Gruß
Johannes

HeinKlocktein, 2021-04-20:
Hallo Johannes,
Entschuldige die späte Antwort. Ich nutze diesen Teil nur zur Verteilung und habe entsprechend nicht bemerkt das Du...
Bist Du weitergekommen?
Im Ordner liegt ein Schaltplan als PDF. Schau Dir den mal an.

Gruß

Michael

Closed 2021-10-04.

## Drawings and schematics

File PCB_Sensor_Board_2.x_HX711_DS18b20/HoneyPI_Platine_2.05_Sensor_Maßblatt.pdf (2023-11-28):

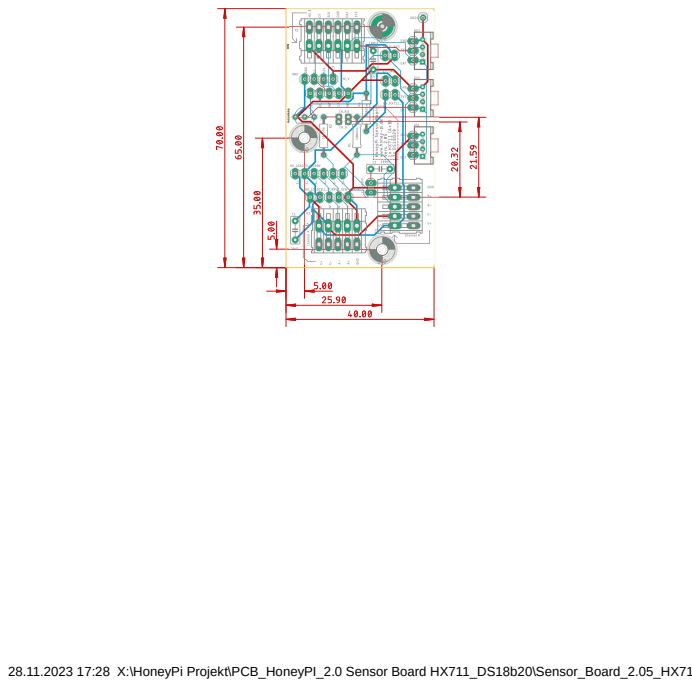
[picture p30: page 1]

28.11.2023 17:28 X:\HoneyPi Projekt\PCB_HoneyPI_2.0 Sensor Board HX711_DS18b20\Sensor_Board_2.05_HX711_DS18b2.brd

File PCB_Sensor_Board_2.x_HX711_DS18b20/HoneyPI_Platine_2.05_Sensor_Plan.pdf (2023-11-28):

# 100Ohm 100nF

A

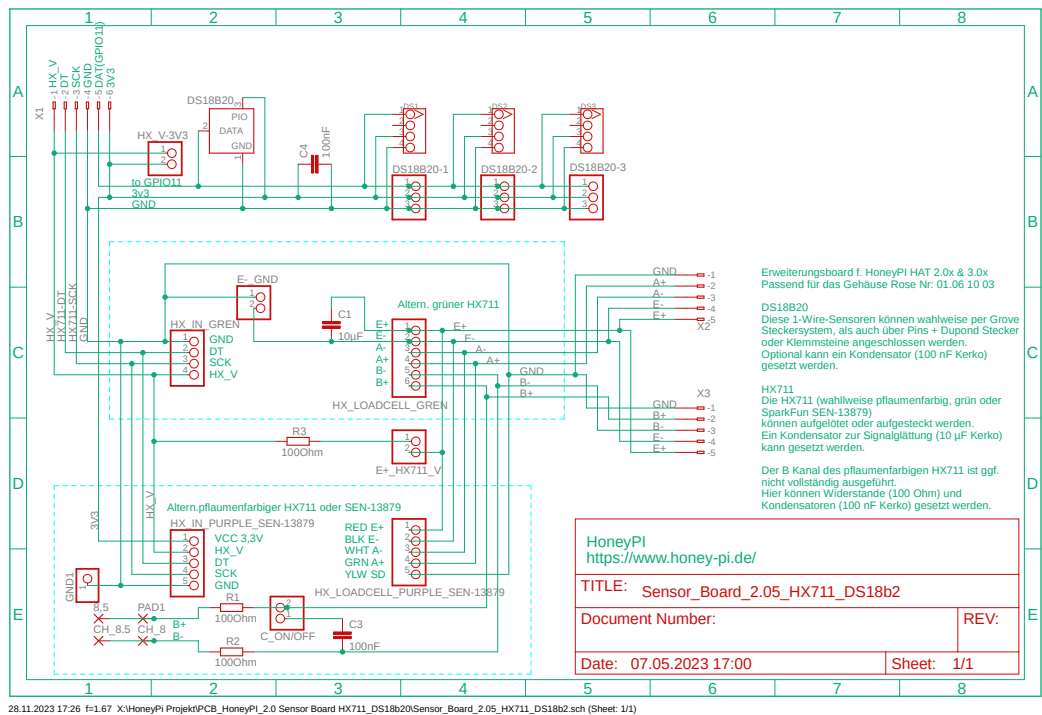
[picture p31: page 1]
100Ohm; HX_IN_GREN; HX_IN_PURPLE_SEN-13879; HX_LOADCELL_GREN; E-_GND; 1 2 3 4 5 HX_LOADCELL_PURPLE_SEN-13879 ¹ GND¹; C_ON/OFF; PIO; GND; DATA 2; PAD1; CH_8.5 HX_V HX⁷¹¹⁻DT; HX_V 3V³ HX⁷¹¹⁻SCK GND; Date:; Sheet:; REV:; Sensor_Board_2.05_HX711_DS18b2; VCC 3,3V HX_V DT SCK GND; GND DT SCK HX_V; to GPIO11; RED E+ BLK E- WHT A- GRN A+ YLW SD; Altern.pflaumenfarbiger HX711 oder SEN-13879; Altern. grüner HX711; 8 HX_V DTSCK GND DAT⁽GPIO¹¹⁾ 3V³

3v3 | | 2 | | 2 | 2
GND | 3 | 3 | 3

Erweiterungsboard f. HoneyPI HAT 2.0x & 3.0x
Passend für das Gehäuse Rose Nr: 01.06 10 03

Diese 1-Wire-Sensoren können wahlweise per Grove
Steckersystem, als auch über Pins + Dupond Stecker
oder Klemmsteine angeschlossen werden.
Optional kann ein Kondensator (100 nF Kerko)
gesetzt werden.

Die HX711 (wahllweise pflaumenfarbig, grün oder
SparkFun SEN-13879)
können aufgelötet oder aufgesteckt werden.
Ein Kondensator zur Signalglättung (10 µF Kerko)
kann gesetzt werden.

Der B Kanal des pflaumenfarbigen HX711 ist ggf.
nicht vollständig ausgeführt.
Hier können Widerstande (100 Ohm) und
Kondensatoren (100 nF Kerko) gesetzt werden.

HoneyPI
https://www.honey-pi.de/
TITLE:
Document Number:

28.11.2023 17:26 f=1.67 X:\HoneyPi Projekt\PCB_HoneyPI_2.0 Sensor Board HX711_DS18b20\Sensor_Board_2.05_HX711_DS18b2.sch (Sheet: 1/1)

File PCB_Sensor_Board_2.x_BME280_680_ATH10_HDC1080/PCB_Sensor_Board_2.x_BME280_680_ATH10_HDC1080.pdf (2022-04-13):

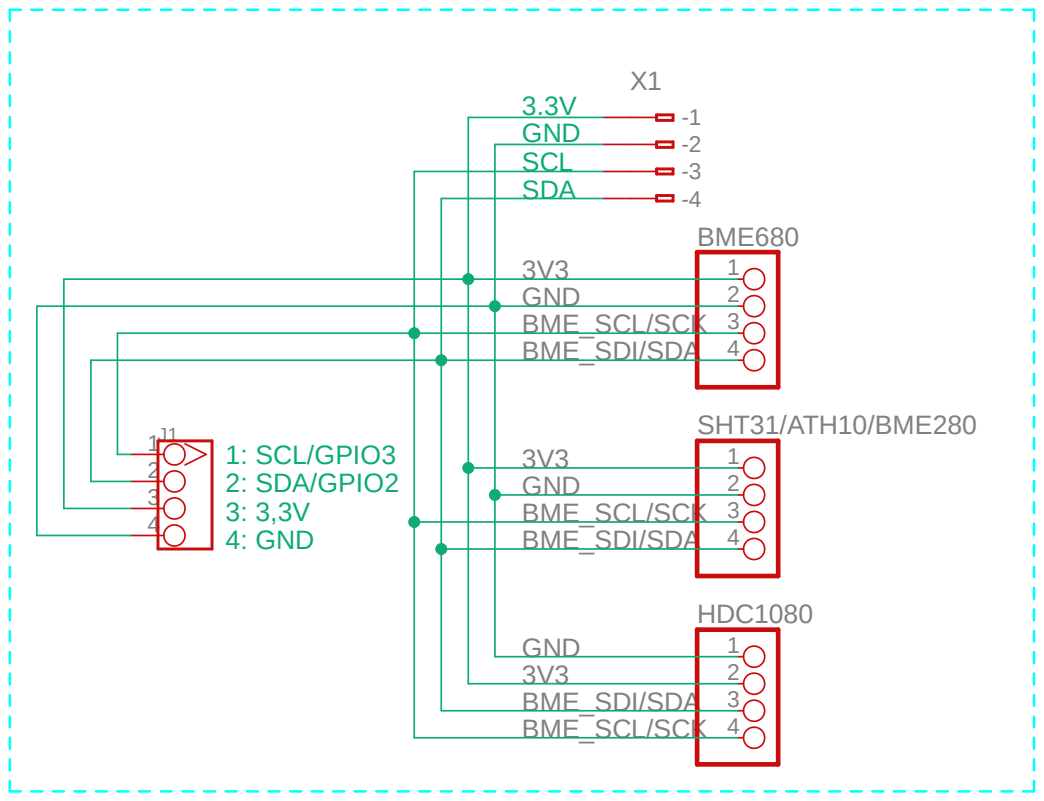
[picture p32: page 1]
BME680; HDC1080; SHT31/ATH10/BME280; BME_SCL/SCK; BME_SDI/SDA; GND; PCB_Sensor_Board_2.x_BME280_680_ATH10_HDC1080; SDA; SCL; 1: SCL/GPIO3 2: SDA/GPIO2 3: 3,3V 4: GND

HoneyPI
https://www.honey-pi.de/
TITLE:

Document Number: | REV:

Date: nicht gespeichert! | Sheet: 1/1

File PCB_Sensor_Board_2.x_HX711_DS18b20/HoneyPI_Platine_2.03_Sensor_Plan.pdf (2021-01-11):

# 100Ohm 100nF

A

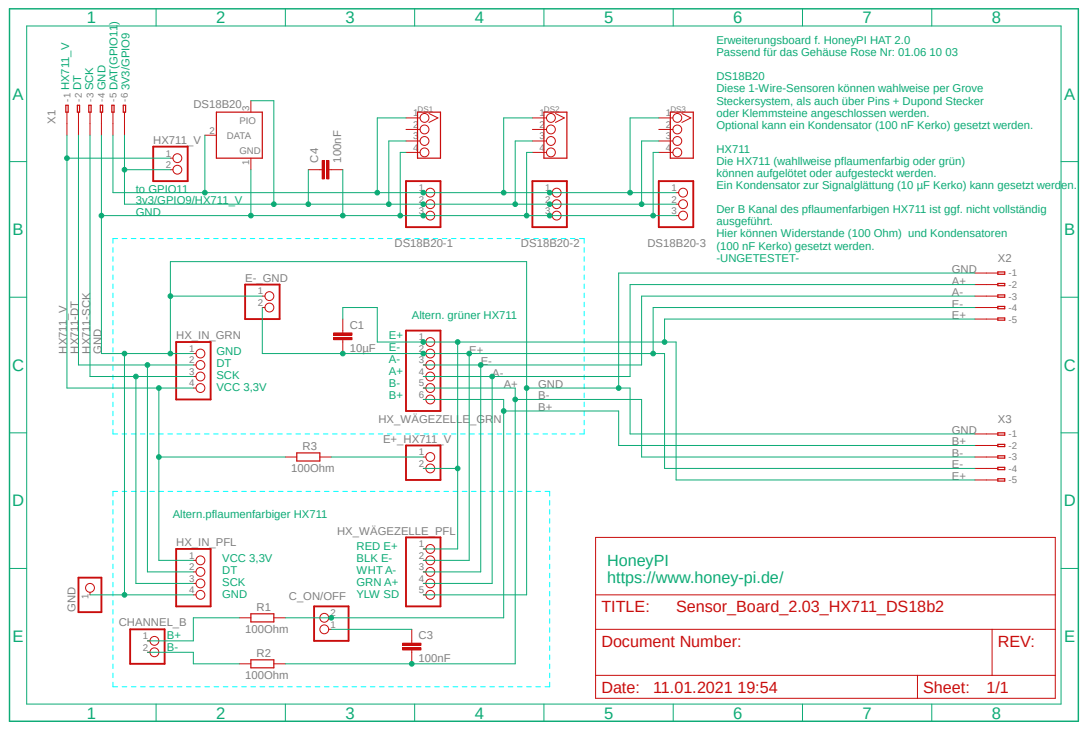
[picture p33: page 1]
100Ohm; HX_IN_GRN; HX_IN_PFL; HX_WÄGEZELLE_GRN; E-_GND; HX_WÄGEZELLE_PFL; CHANNEL_B; 1 GND; C_ON/OFF; PIO; GND; DATA 2; Date:; Sheet:; REV:; Document Number:; Sensor_Board_2.03_HX711_DS18b2; 3v3/GPIO9/HX711_V; VCC 3,3V DT SCK GND; GND DT SCK VCC 3,3V; to GPIO11; RED E+ BLK E- WHT A- GRN A+ YLW SD; Altern.pflaumenfarbiger HX711; Altern. grüner HX711; 8 HX⁷¹¹_V DTSCK GND DAT⁽GPIO¹¹⁾ 3V³/GPIO⁹

Erweiterungsboard f. HoneyPI HAT 2.0
Passend für das Gehäuse Rose Nr: 01.06 10 03

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

Die HX711 (wahllweise pflaumenfarbig oder grün)
können aufgelötet oder aufgesteckt werden.
Ein Kondensator zur Signalglättung (10 µF Kerko) kann gesetzt werden.

Der B Kanal des pflaumenfarbigen HX711 ist ggf. nicht vollständig
ausgeführt.
Hier können Widerstande (100 Ohm) und Kondensatoren
(100 nF Kerko) gesetzt werden.
-UNGETESTET-

R3 HX⁷¹¹_V HX⁷¹¹⁻DT HX⁷¹¹⁻SCK GND

2 | | 3 4 5 6

HoneyPI
https://www.honey-pi.de/
TITLE:

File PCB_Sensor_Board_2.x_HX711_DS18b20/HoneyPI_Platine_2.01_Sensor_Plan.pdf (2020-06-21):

A

A

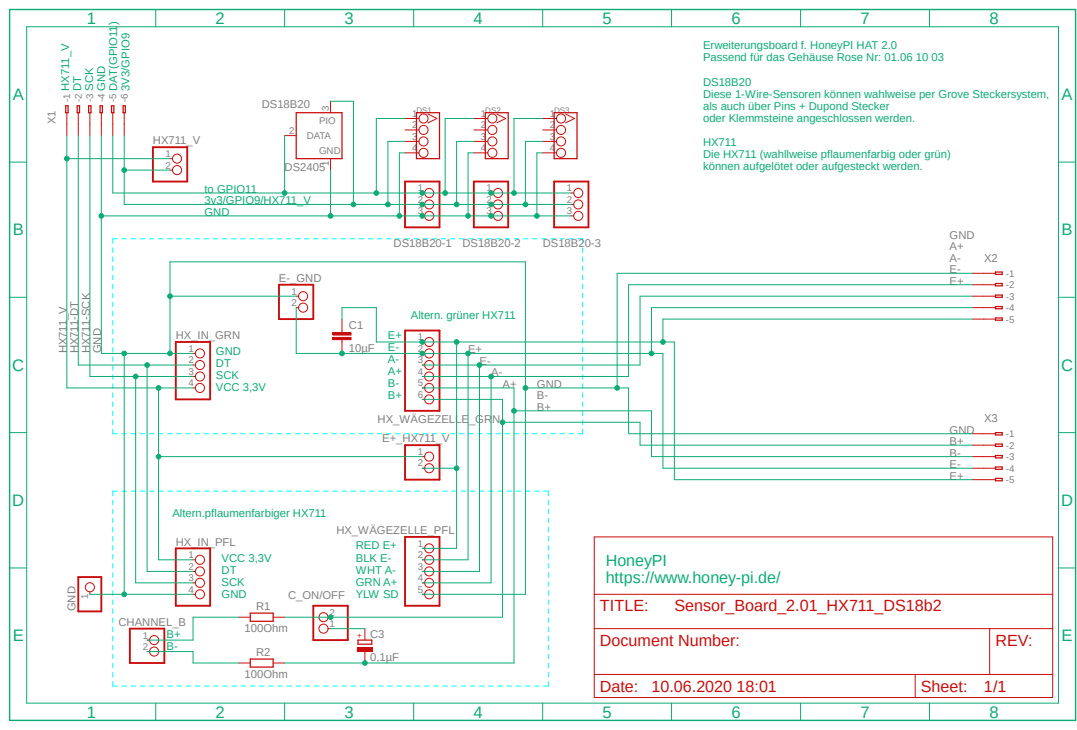
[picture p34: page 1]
100Ohm; HX_IN_GRN; HX_IN_PFL; HX_WÄGEZELLE_GRN; E-_GND; HX_WÄGEZELLE_PFL; CHANNEL_B; 1 GND; C_ON/OFF; PIO; GND; DATA 2; 1 3DS18B20 HX⁷¹¹_V HX⁷¹¹⁻DT HX⁷¹¹⁻SCK GND; Date:; Sheet:; REV:; Sensor_Board_2.01_HX711_DS18b2 +; 3v3/GPIO9/HX711_V; VCC 3,3V DT SCK GND; GND DT SCK VCC 3,3V; to GPIO11; RED E+ BLK E- WHT A- GRN A+ YLW SD; Altern.pflaumenfarbiger HX711; Altern. grüner HX711; 8 HX⁷¹¹_V DTSCK GND DAT⁽GPIO¹¹⁾ 3V³/GPIO⁹

Erweiterungsboard f. HoneyPI HAT 2.0
Passend für das Gehäuse Rose Nr: 01.06 10 03

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

Die HX711 (wahllweise pflaumenfarbig oder grün)
können aufgelötet oder aufgesteckt werden.

2 | 3 4 5 6 | GND

HoneyPI
https://www.honey-pi.de/
TITLE:
Document Number:

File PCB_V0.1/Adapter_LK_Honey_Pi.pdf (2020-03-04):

A

A

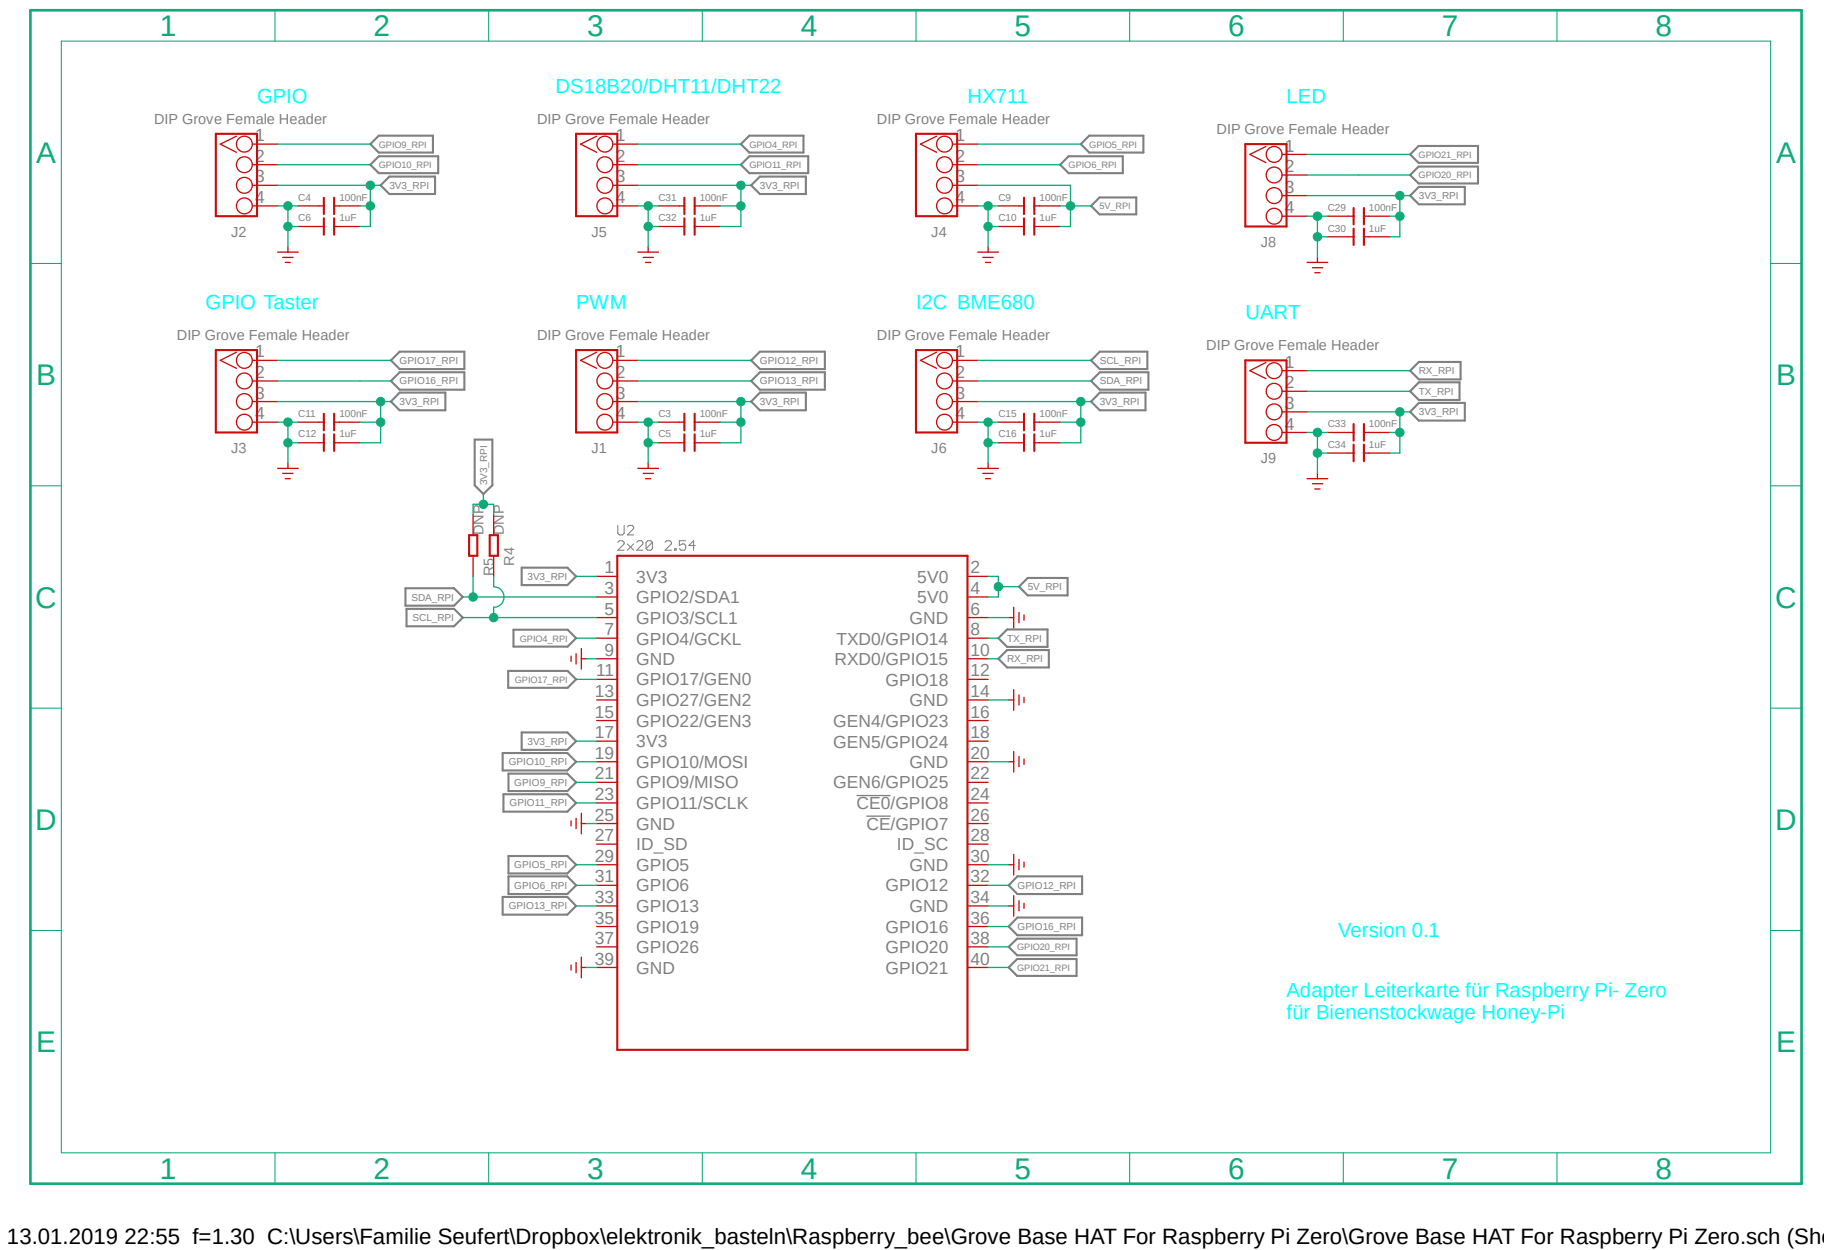
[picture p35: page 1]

DIP Grove Female Header

Adapter Leiterkarte für Raspberry Pi- Zero
für Bienenstockwage Honey-Pi

13.01.2019 22:55 f=1.30 C:\Users\Familie Seufert\Dropbox\elektronik_basteln\Raspberry_bee\Grove Base HAT For Raspberry Pi Zero\Grove Base HAT For Raspberry Pi Zero.sch (Sheet: 1/1)

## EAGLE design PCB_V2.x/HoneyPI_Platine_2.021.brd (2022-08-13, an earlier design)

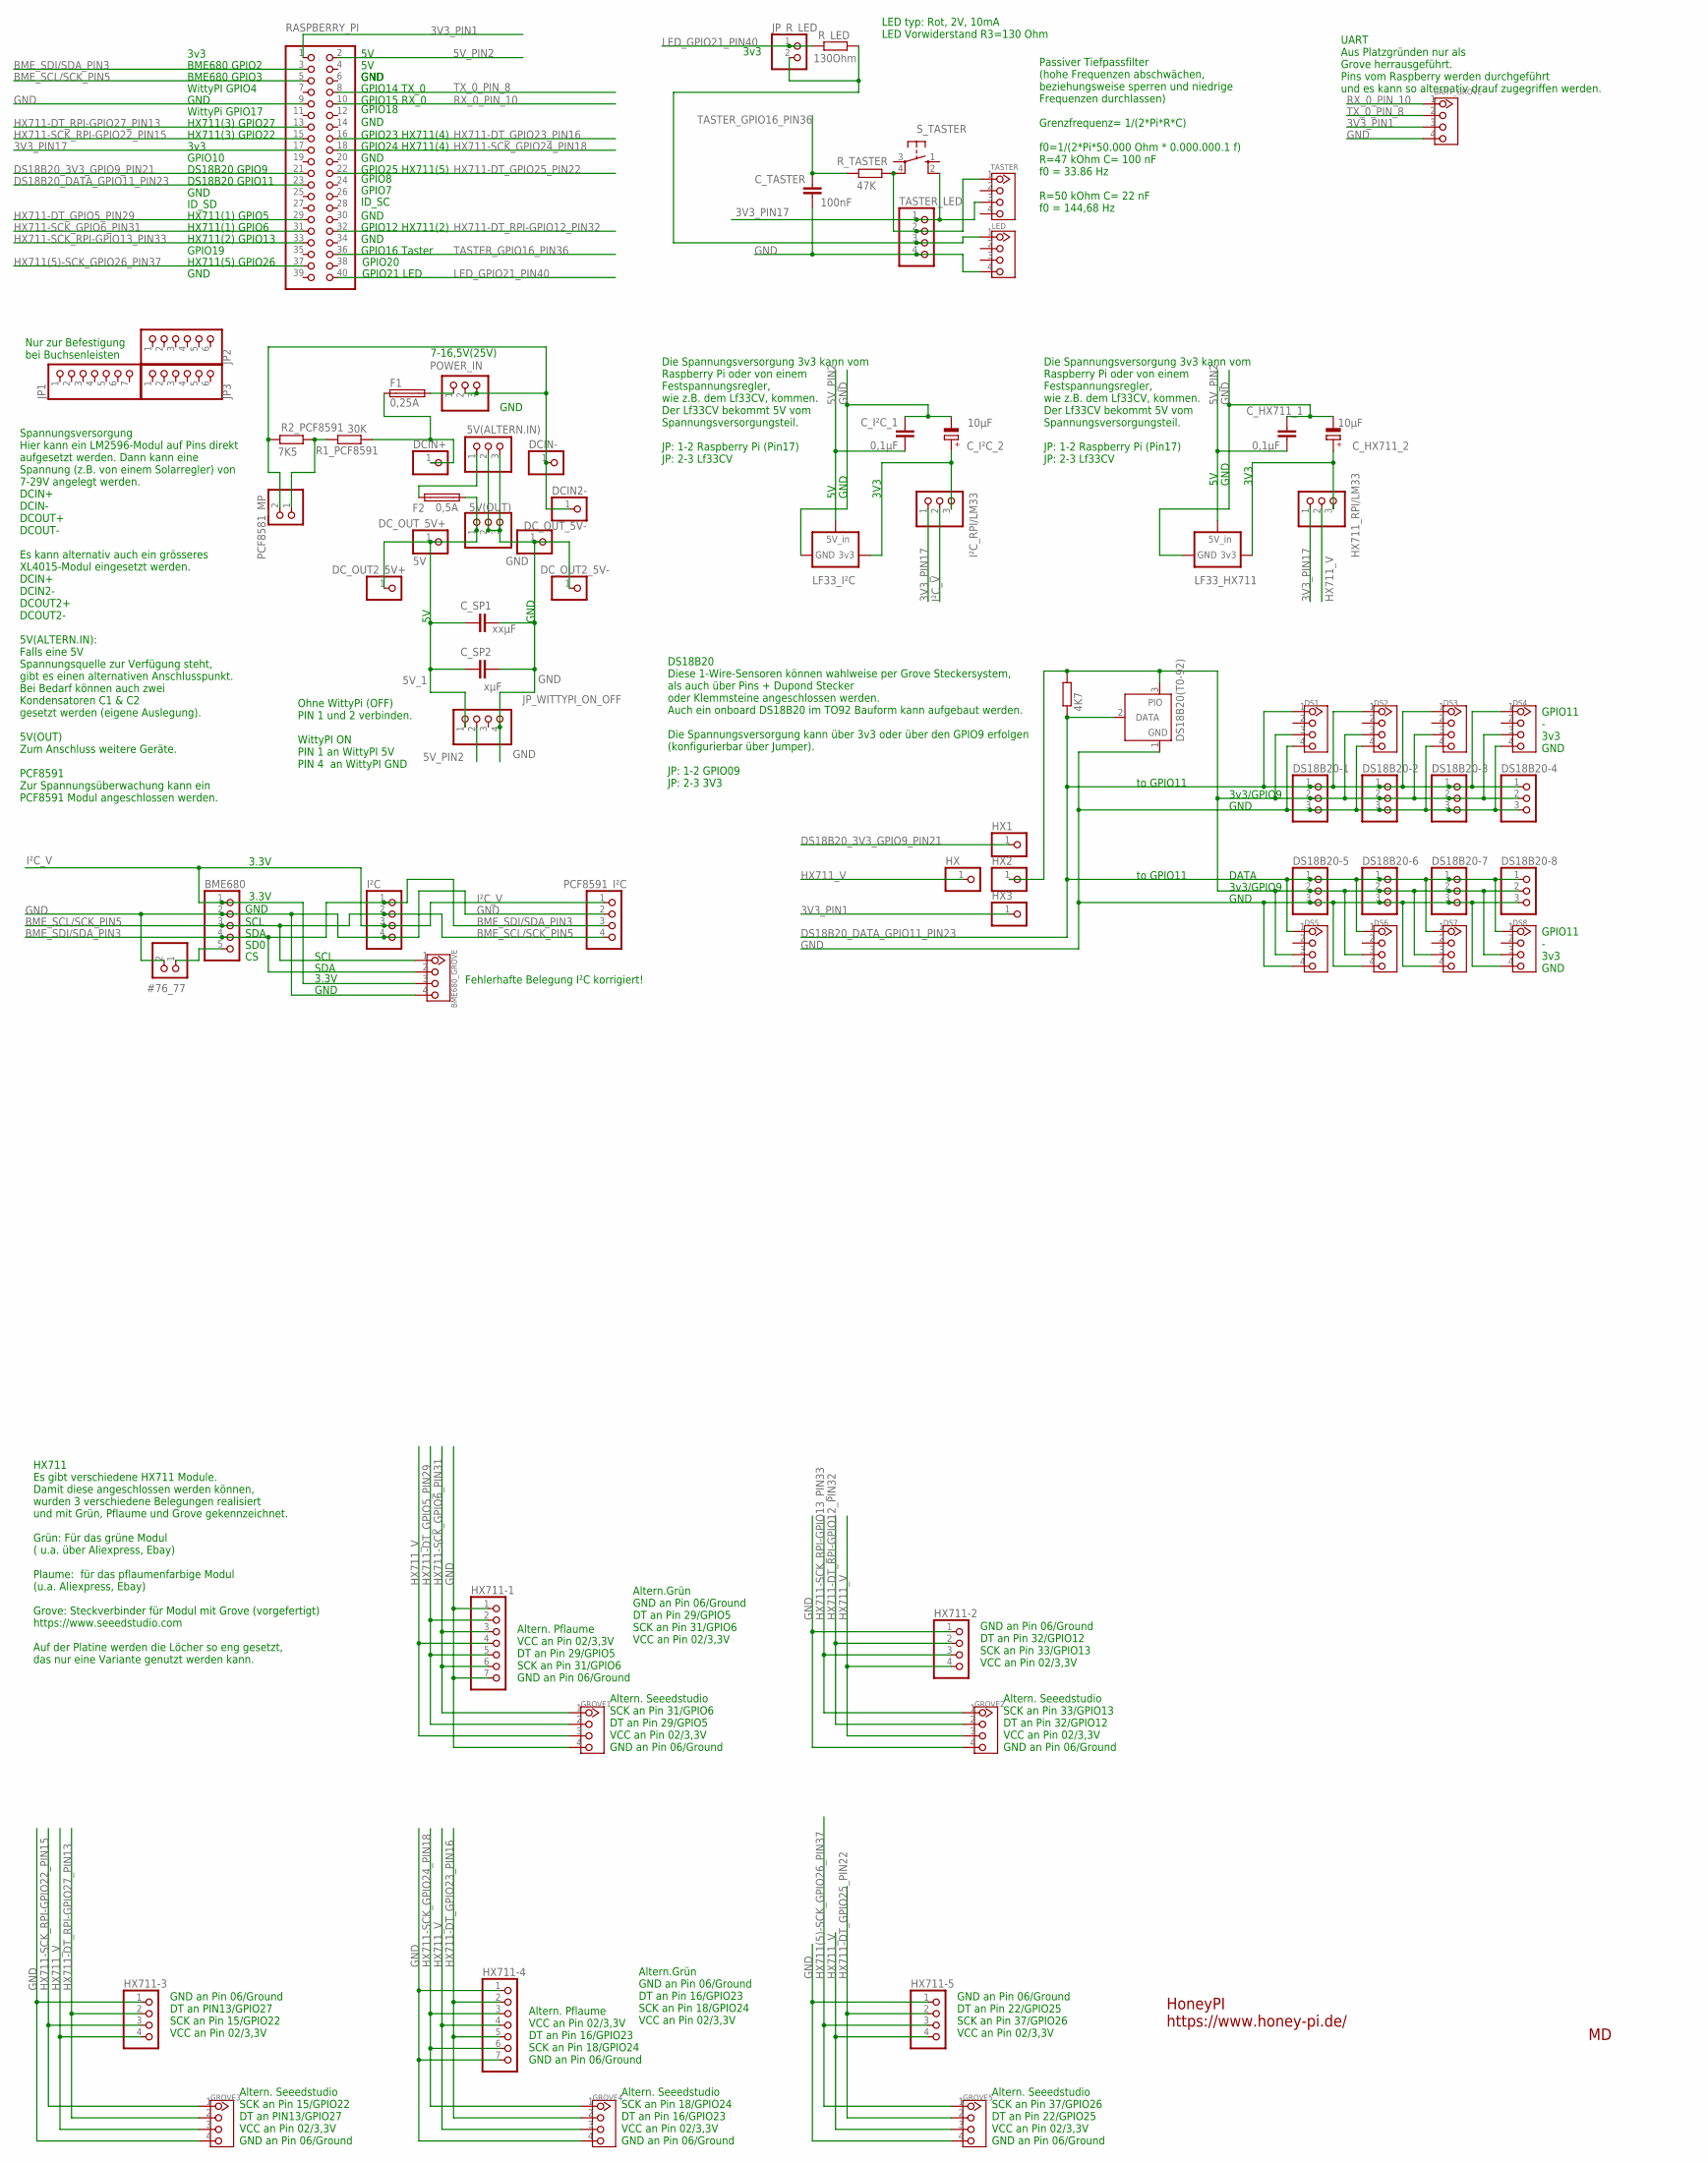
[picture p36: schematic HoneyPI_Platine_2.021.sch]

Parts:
5V(ALTERN.IN), 5V(OUT): PINHD-1X3; 1X03
#76_77: PINHD-1X2; 1X02
BME680: PINHD-1X5; 1X05
BME680_GROVE: TWIG-4P-2.0-2.0; 4P-2.0
C_HX711_1: 0,1µF; C2.5-3
C_HX711_2: 10µF; E2-5
C_I²C_1: 0,1µF; C2.5-3
C_I²C_2: 10µF; E2-5
C_SP1: xxµF; C2.5-3
C_SP2: xµF; C2.5-3
C_TASTER: 100nF; C2.5-3
DCIN2-: PINHD-1X1; 1X01
DCIN+: PINHD-1X1; 1X01
DCIN-: PINHD-1X1; 1X01
DC_OUT2_5V+, DC_OUT2_5V-: PINHD-1X1; 1X01
DC_OUT_5V+: 5V; 1X01
DC_OUT_5V-: GND; 1X01
DS1, DS2, DS3, DS4, DS5, DS6, DS7, DS8: TWIG-4P-2.0-2.0; 4P-2.0
DS18B20(T0-92): DS18b20; TO92-
DS18B20-1, DS18B20-2, DS18B20-3, DS18B20-4, DS18B20-5, DS18B20-6, DS18B20-7, DS18B20-8: PINHD-1X3; 1X03
F1: 0,25A; TR5
F2: 0,5A; TR5
GROVE1, GROVE2, GROVE3, GROVE4, GROVE5: TWIG-4P-2.0-2.0; 4P-2.0
HX, HX1, HX2, HX3: PINHD-1X1; 1X01
HX711-1, HX711-4: PINHD-1X7; 1X07
HX711-2, HX711-3, HX711-5: PINHD-1X4; 1X04
HX711_RPI/LM33: PINHD-1X3; 1X03
I²C: PINHD-1X4; 1X04
I²C_RPI/LM33: PINHD-1X3; 1X03
JP1: PINHD-1X7; 1X07
JP2, JP3: PINHD-1X6; 1X06
JP_R_LED: PINHD-1X2; 1X02
JP_WITTYPI_ON_OFF: PINHD-1X4; 1X04
LED: TWIG-4P-2.0-2.0; 4P-2.0
LF33_HX711, LF33_I²C: LM33CV; 337TS
PCF8581_MP: PINHD-1X2; 1X02
PCF8591_I²C: PINHD-1X4; 1X04
POWER_IN: PINHD-1X3; 1X03
R1_PCF8591: 30K; 0204/7
R2_PCF8591: 7K5; 0204/7
RASPBERRY_PI: PINHD-2X20; 2X20
R_DS18B20: 4K7; 0204/7
R_LED: 130Ohm; 0204/7
R_TASTER: 47K; 0204/7
S_TASTER: 10-XX; B3F-10XX
TASTER: TWIG-4P-2.0-2.0; 4P-2.0
TASTER_LED: PINHD-1X4; 1X04
UART_GROVE: TWIG-4P-2.0-2.0; 4P-2.0

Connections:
3V3: DS1.3, DS2.3, DS3.3, DS4.3, DS5.3, DS6.3, DS7.3, DS8.3, DS18B20(T0-92).3 (PIO), DS18B20-1.2, DS18B20-2.2, DS18B20-3.2, DS18B20-4.2, DS18B20-5.2, DS18B20-6.2, DS18B20-7.2, DS18B20-8.2, HX2.1, R_DS18B20.2
3V3_PIN1: HX3.1, RASPBERRY_PI.1, UART_GROVE.3
3V3_PIN17: HX711_RPI/LM33.1, I²C_RPI/LM33.1, RASPBERRY_PI.17, S_TASTER.2 (S1), TASTER.3, TASTER_LED.1
5V_1: 5V(OUT).1, C_SP1.1, C_SP2.1, DC_OUT2_5V+.1, DC_OUT_5V+.1, F2.1, JP_WITTYPI_ON_OFF.1
5V_PIN2: C_HX711_1.1, C_I²C_1.1, JP_WITTYPI_ON_OFF.2, LF33_HX711.1 (5V), LF33_I²C.1 (5V), RASPBERRY_PI.2
BME_SCL/SCK_PIN5: BME680.3, BME680_GROVE.1, I²C.2, PCF8591_I²C.4, RASPBERRY_PI.5
BME_SDI/SDA_PIN3: BME680.4, BME680_GROVE.2, I²C.1, PCF8591_I²C.3, RASPBERRY_PI.3
DS18B20_3V3_GPIO9_PIN21: HX1.1, RASPBERRY_PI.21
DS18B20_DATA_GPIO11_PIN23: DS1.1, DS2.1, DS3.1, DS4.1, DS5.1, DS6.1, DS7.1, DS8.1, DS18B20(T0-92).2 (DATA), DS18B20-1.1, DS18B20-2.1, DS18B20-3.1, DS18B20-4.1, DS18B20-5.1, DS18B20-6.1, DS18B20-7.1, DS18B20-8.1, RASPBERRY_PI.23, R_DS18B20.1
GND: 5V(ALTERN.IN).2, 5V(ALTERN.IN).3, 5V(OUT).2, 5V(OUT).3, #76_77.2, BME680.2, BME680_GROVE.4, C_HX711_1.2, C_HX711_2.-, C_I²C_1.2, C_I²C_2.-, C_SP1.2, C_SP2.2, C_TASTER.1, DC_OUT2_5V-.1, DC_OUT_5V-.1, DS1.4, DS2.4, DS3.4, DS4.4, DS5.4, DS6.4, DS7.4, DS8.4, DS18B20(T0-92).1 (GND), DS18B20-1.3, DS18B20-2.3, DS18B20-3.3, DS18B20-4.3, DS18B20-5.3, DS18B20-6.3, DS18B20-7.3, DS18B20-8.3, GROVE1.4, GROVE2.4, GROVE3.4, GROVE4.4, GROVE5.4, HX711-1.1, HX711-1.7, HX711-2.1, HX711-3.1, HX711-4.1, HX711-4.7, HX711-5.1, I²C.4, JP_WITTYPI_ON_OFF.4, LED.4, LF33_HX711.2 (GND), LF33_I²C.2 (GND), PCF8591_I²C.2, RASPBERRY_PI.9, TASTER_LED.4, UART_GROVE.4
GND20V: DCIN2-.1, DCIN-.1, PCF8581_MP.2, POWER_IN.2, POWER_IN.3, R2_PCF8591.2
HX711(5)-SCK_GPIO26_PIN37: GROVE5.1, HX711-5.3, RASPBERRY_PI.37
HX711-DT_GPIO5_PIN29: GROVE1.2, HX711-1.2, HX711-1.5, RASPBERRY_PI.29
HX711-DT_GPIO23_PIN16: GROVE4.2, HX711-4.2, HX711-4.5, RASPBERRY_PI.16
HX711-DT_GPIO25_PIN22: GROVE5.2, HX711-5.2, RASPBERRY_PI.22
HX711-DT_RPI-GPIO12_PIN32: GROVE2.2, HX711-2.2, RASPBERRY_PI.32
HX711-DT_RPI-GPIO27_PIN13: GROVE3.2, HX711-3.2, RASPBERRY_PI.13
HX711-SCK_GPIO6_PIN31: GROVE1.1, HX711-1.3, HX711-1.6, RASPBERRY_PI.31
HX711-SCK_GPIO24_PIN18: GROVE4.1, HX711-4.3, HX711-4.6, RASPBERRY_PI.18
HX711-SCK_RPI-GPIO13_PIN33: GROVE2.1, HX711-2.3, RASPBERRY_PI.33
HX711-SCK_RPI-GPIO22_PIN15: GROVE3.1, HX711-3.3, RASPBERRY_PI.15
HX711_V: GROVE1.3, GROVE2.3, GROVE3.3, GROVE4.3, GROVE5.3, HX.1, HX711-1.4, HX711-2.4, HX711-3.4, HX711-4.4, HX711-5.4, HX711_RPI/LM33.2
I²C_V: BME680.1, BME680_GROVE.3, I²C.3, I²C_RPI/LM33.2, PCF8591_I²C.1
LED_2: JP_R_LED.2, LED.1, R_LED.2, TASTER_LED.3
LED_GPIO21_PIN40: JP_R_LED.1, RASPBERRY_PI.40, R_LED.1
unnamed: C_I²C_2.+, I²C_RPI/LM33.3, LF33_I²C.3 (OUT3V3)
unnamed: R_TASTER.1, S_TASTER.4 (P1), TASTER.1, TASTER_LED.2
unnamed: C_HX711_2.+, HX711_RPI/LM33.3, LF33_HX711.3 (OUT3V3)
unnamed: #76_77.1, BME680.5
unnamed: 5V(ALTERN.IN).1, F2.2
RX_0_PIN_10: RASPBERRY_PI.10, UART_GROVE.1
SPANNUNGSTEILER1: PCF8581_MP.1, R1_PCF8591.2, R2_PCF8591.1
TASTER_GPIO16_PIN36: C_TASTER.2, RASPBERRY_PI.36, R_TASTER.2
TX_0_PIN_8: RASPBERRY_PI.8, UART_GROVE.2
VDD20V1: DCIN+.1, F1.1, R1_PCF8591.1
VDD20V2: F1.2, POWER_IN.1

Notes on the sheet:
3v3
3v3/GPIO9
DATA
GND
SCL
SDA
SD0
7-16,5V(25V)
Altern. Pflaume VCC an Pin 02/3,3V DT an Pin 29/GPIO5 SCK an Pin 31/GPIO6 GND an Pin 06/Ground
GPIO18
Altern.Grün GND an Pin 06/Ground DT an Pin 29/GPIO5 SCK an Pin 31/GPIO6 VCC an Pin 02/3,3V
BME680 GPIO2
BME680 GPIO3
WittyPI GPIO4
WittyPi GPIO17
DS18B20 GPIO9
DS18B20 GPIO11
HX711(1) GPIO5
HX711(1) GPIO6
HX711(2) GPIO13
GPIO16 Taster
GPIO21 LED
GPIO12 HX711(2)
to GPIO11
GPIO11 - 3v3 GND
GPIO23 HX711(4)
GPIO24 HX711(4)
GPIO25 HX711(5)
HX711(5) GPIO26
GPIO15 RX_0
GPIO14 TX_0
HX711(3) GPIO27
HX711(3) GPIO22
Altern. Seeedstudio SCK an Pin 31/GPIO6 DT an Pin 29/GPIO5 VCC an Pin 02/3,3V GND an Pin 06/Ground
GND an Pin 06/Ground DT an Pin 32/GPIO12 SCK an Pin 33/GPIO13 VCC an Pin 02/3,3V
Altern. Seeedstudio SCK an Pin 33/GPIO13 DT an Pin 32/GPIO12 VCC an Pin 02/3,3V GND an Pin 06/Ground
GND an Pin 06/Ground DT an PIN13/GPIO27 SCK an Pin 15/GPIO22 VCC an Pin 02/3,3V
Altern. Seeedstudio SCK an Pin 15/GPIO22 DT an PIN13/GPIO27 VCC an Pin 02/3,3V GND an Pin 06/Ground
Altern. Pflaume VCC an Pin 02/3,3V DT an Pin 16/GPIO23 SCK an Pin 18/GPIO24 GND an Pin 06/Ground
Altern.Grün GND an Pin 06/Ground DT an Pin 16/GPIO23 SCK an Pin 18/GPIO24 VCC an Pin 02/3,3V

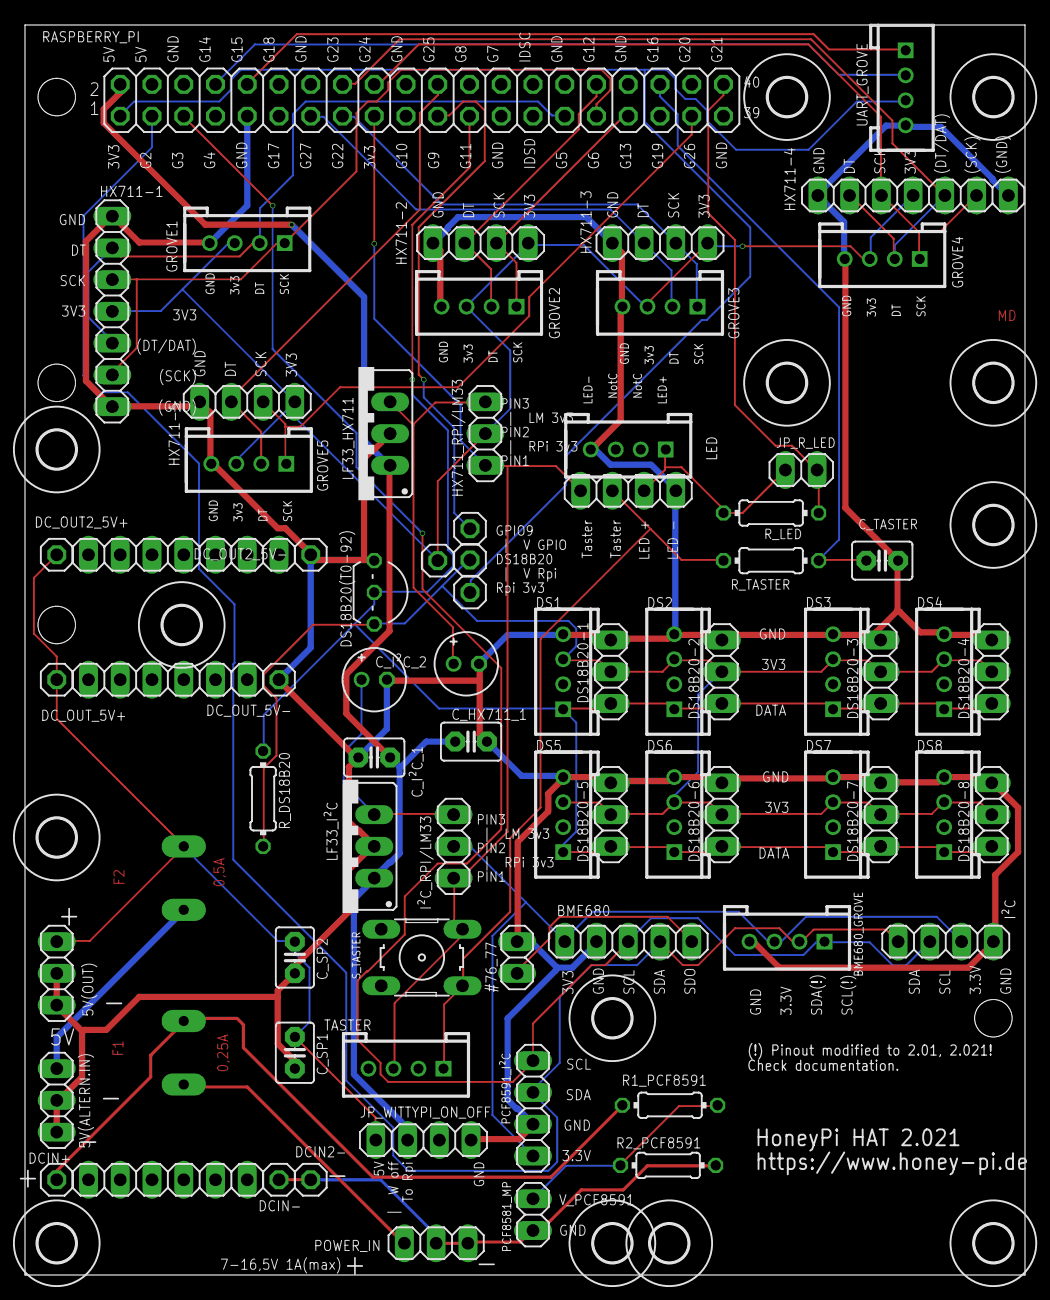
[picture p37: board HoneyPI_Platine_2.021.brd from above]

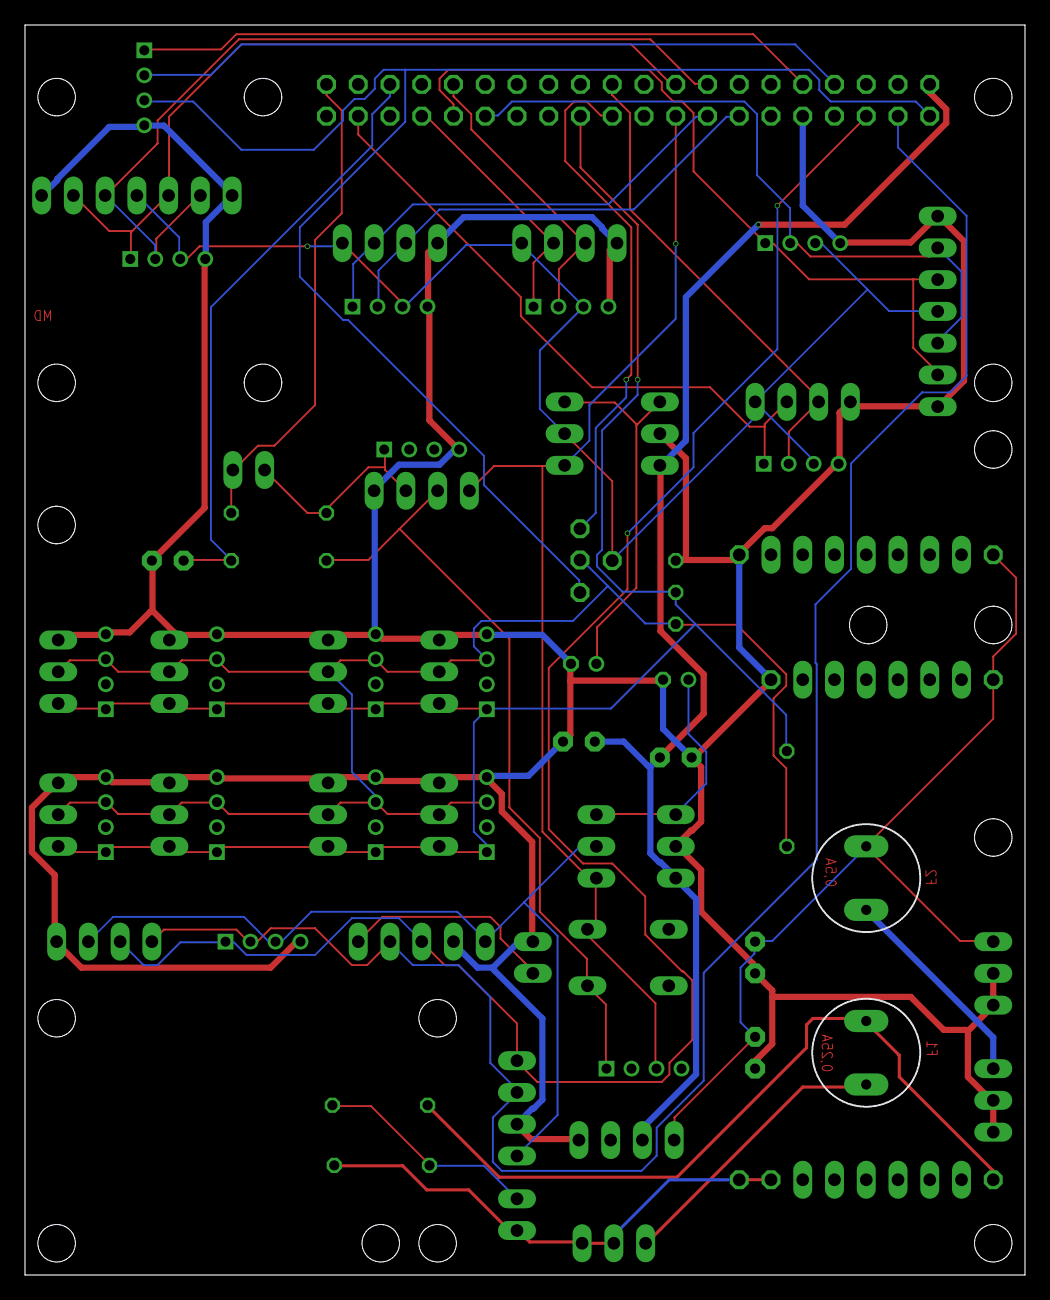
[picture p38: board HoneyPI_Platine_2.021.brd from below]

Board: 2 copper layers, 80.0 x 100.0 mm, 89 parts (2 on the bottom side), 36 nets.

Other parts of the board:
U$1, U$2, U$3, U$4, U$5, U$6, U$7, U$8, U$9, U$10, U$11, U$12, U$13: 3,0

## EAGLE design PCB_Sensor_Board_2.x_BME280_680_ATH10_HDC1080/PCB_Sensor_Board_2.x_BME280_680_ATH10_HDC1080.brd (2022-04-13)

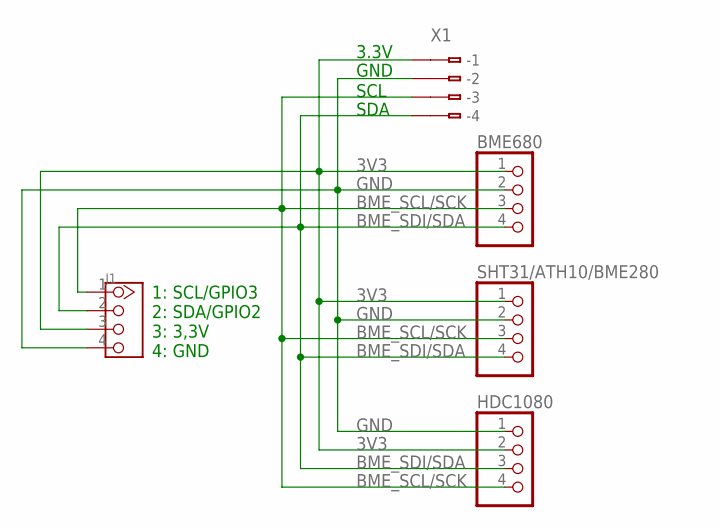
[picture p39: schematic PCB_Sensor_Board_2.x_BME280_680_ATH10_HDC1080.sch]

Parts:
BME680: PINHD-1X4; 1X04
HDC1080: PINHD-1X4; 1X04
J1: TWIG-4P-2.0-2.0; 4P-2.0
SHT31/ATH10/BME280: PINHD-1X4; 1X04
X1: 233-504

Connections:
3V3: BME680.1, HDC1080.2, J1.3, SHT31/ATH10/BME280.1, X1.B1 (B-1)
BME_SCL/SCK: BME680.3, HDC1080.4, J1.1, SHT31/ATH10/BME280.3, X1.B3 (B-3)
BME_SDI/SDA: BME680.4, HDC1080.3, J1.2, SHT31/ATH10/BME280.4, X1.B4 (B-4)
GND: BME680.2, HDC1080.1, J1.4, SHT31/ATH10/BME280.2, X1.B2 (B-2)

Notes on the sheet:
GND
SDA
SCL
3.3V
1: SCL/GPIO3 2: SDA/GPIO2 3: 3,3V 4: GND

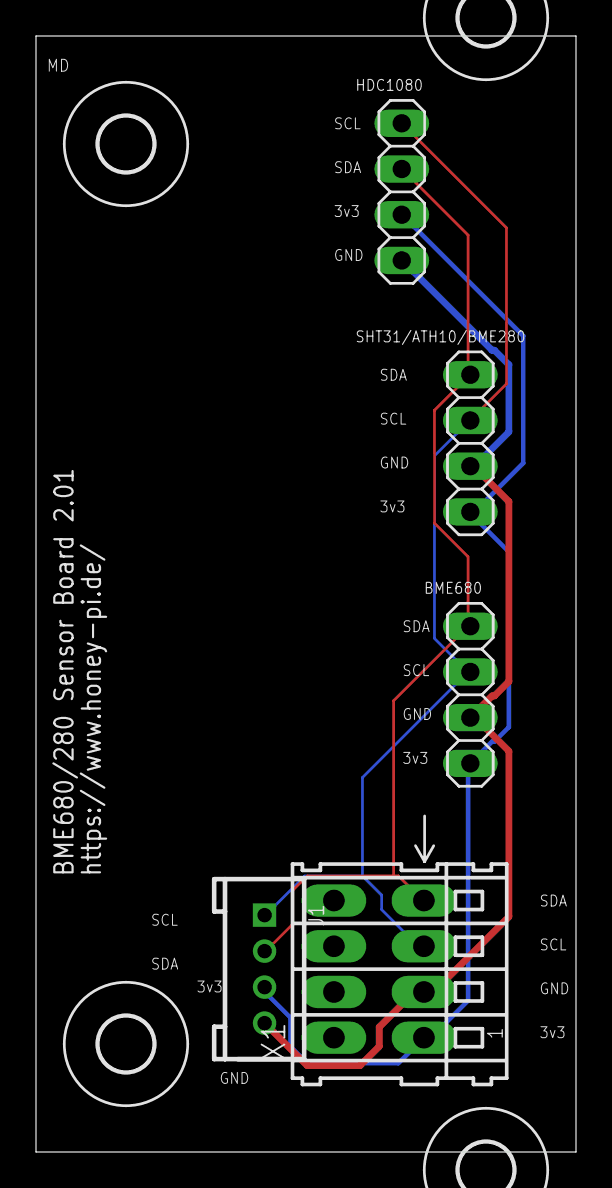
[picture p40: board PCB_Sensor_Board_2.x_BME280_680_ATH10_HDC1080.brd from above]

Board: 2 copper layers, 30.0 x 62.0 mm, 9 parts (0 on the bottom side), 4 nets.

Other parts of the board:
U$1, U$2, U$3, U$4: 3,0

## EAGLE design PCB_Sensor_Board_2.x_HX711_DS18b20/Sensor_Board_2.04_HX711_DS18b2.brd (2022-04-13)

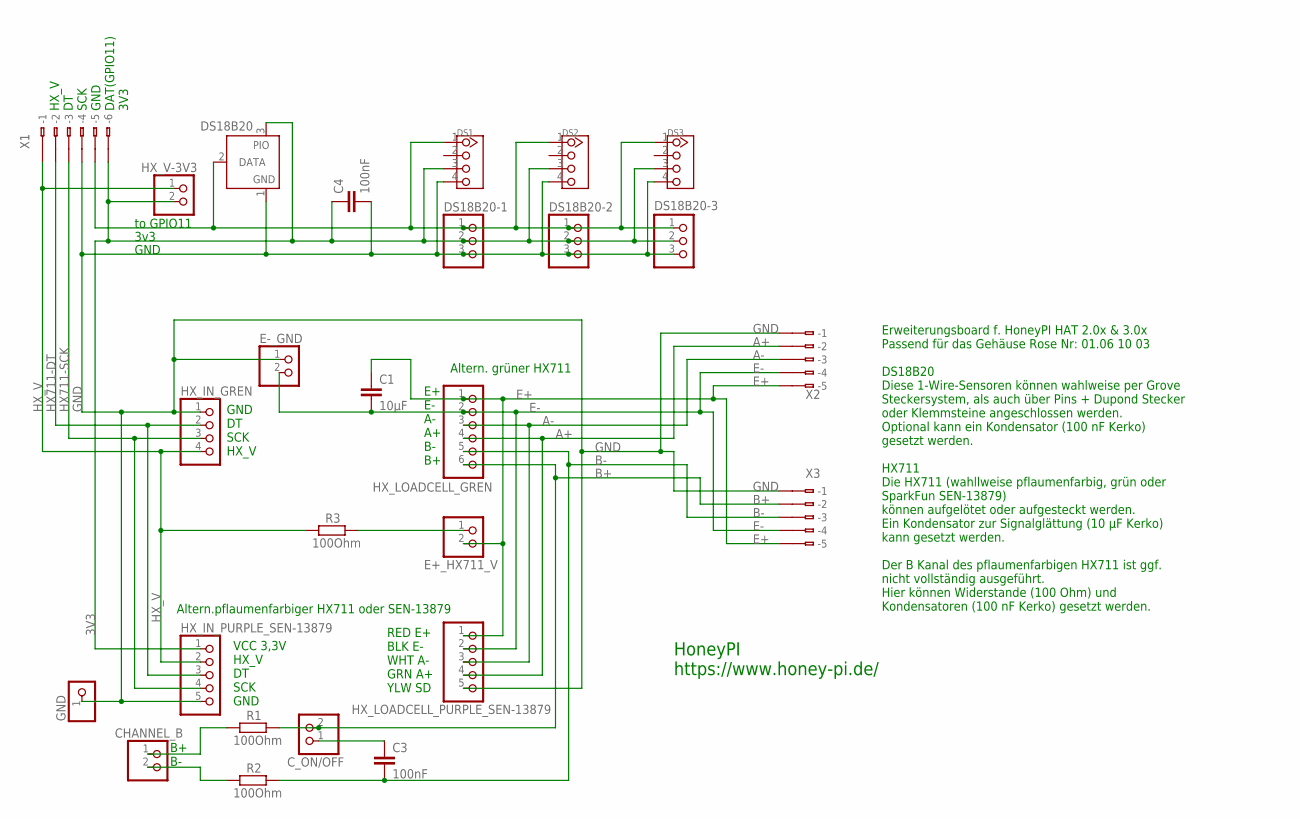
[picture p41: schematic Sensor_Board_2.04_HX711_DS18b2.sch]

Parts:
C1: 10µF; C5B2.5
C3, C4: 100nF; C5B2.5
CHANNEL_B: PINHD-1X2; 1X02
C_ON/OFF: PINHD-1X2; 1X02
DS1, DS2, DS3: TWIG-4P-2.0-2.0; 4P-2.0
DS18B20: DS2405; TO92-
DS18B20-1, DS18B20-2, DS18B20-3: PINHD-1X3; 1X03
E+_HX711_V: PINHD-1X2; 1X02
E-_GND: PINHD-1X2; 1X02
GND: PINHD-1X1; 1X01
HX_IN_GREN: PINHD-1X4; 1X04
HX_IN_PURPLE_SEN-13879: PINHD-1X5; 1X05
HX_LOADCELL_GREN: PINHD-1X6; 1X06
HX_LOADCELL_PURPLE_SEN-13879: PINHD-1X5; 1X05
HX_V-3V3: PINHD-1X2; 1X02
R1, R2, R3: 100Ohm; 0207/10
X1: 233-506
X2, X3: 233-505

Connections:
3V3: C4.1, DS1.3, DS2.3, DS3.3, DS18B20.3 (PIO), DS18B20-1.2, DS18B20-2.2, DS18B20-3.2, HX_IN_PURPLE_SEN-13879.1, HX_V-3V3.2, X1.B6 (B-6)
A+: HX_LOADCELL_GREN.4, HX_LOADCELL_PURPLE_SEN-13879.4, X2.B2 (B-2)
A-: HX_LOADCELL_GREN.3, HX_LOADCELL_PURPLE_SEN-13879.3, X2.B3 (B-3)
B+: C_ON/OFF.2, HX_LOADCELL_GREN.6, R1.2, X3.B2 (B-2)
B-: C3.2, HX_LOADCELL_GREN.5, R2.2, X3.B3 (B-3)
DS18B20_DATA_GPIO11_PIN23: DS1.1, DS2.1, DS3.1, DS18B20.2 (DATA), DS18B20-1.1, DS18B20-2.1, DS18B20-3.1, X1.B5 (B-5)
E+: C1.1, E+_HX711_V.2, HX_LOADCELL_GREN.1, HX_LOADCELL_PURPLE_SEN-13879.1, X2.B5 (B-5), X3.B5 (B-5)
E-: C1.2, E-_GND.2, HX_LOADCELL_GREN.2, HX_LOADCELL_PURPLE_SEN-13879.2, X2.B4 (B-4), X3.B4 (B-4)
GND: C4.2, DS1.4, DS2.4, DS3.4, DS18B20.1 (GND), DS18B20-1.3, DS18B20-2.3, DS18B20-3.3, E-_GND.1, GND.1, HX_IN_GREN.1, HX_IN_PURPLE_SEN-13879.5, HX_LOADCELL_PURPLE_SEN-13879.5, X1.B4 (B-4), X2.B1 (B-1), X3.B1 (B-1)
HX711-DT: HX_IN_GREN.2, HX_IN_PURPLE_SEN-13879.3, X1.B2 (B-2)
HX711-SCK: HX_IN_GREN.3, HX_IN_PURPLE_SEN-13879.4, X1.B3 (B-3)
HX_V: HX_IN_GREN.4, HX_IN_PURPLE_SEN-13879.2, HX_V-3V3.1, R3.1, X1.B1 (B-1)
unnamed: CHANNEL_B.1, R1.1
unnamed: CHANNEL_B.2, R2.1
unnamed: C3.1, C_ON/OFF.1
unnamed: E+_HX711_V.1, R3.2

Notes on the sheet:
3v3
VCC 3,3V HX_V DT SCK GND
GND DT SCK HX_V
GND
to GPIO11
Erweiterungsboard f. HoneyPI HAT 2.0x & 3.0x Passend für das Gehäuse Rose Nr: 01.06 10 03 DS18B20 Diese 1-Wire-Sensoren können wahlweise per Grove Steckersystem, als auch über Pins + Dupond Stecker oder Klemmsteine angeschlossen werden. Optional kann ein Kondensator (100 nF Kerko) gesetzt werden. H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
E+ E- A- A+ B- B+
RED E+ BLK E- WHT A- GRN A+ YLW SD
B+ B-
Altern.pflaumenfarbiger HX711 oder SEN-13879
Altern. grüner HX711
HX_V DT SCK GND DAT(GPIO11) 3V3
HoneyPI https://www.honey-pi.de/

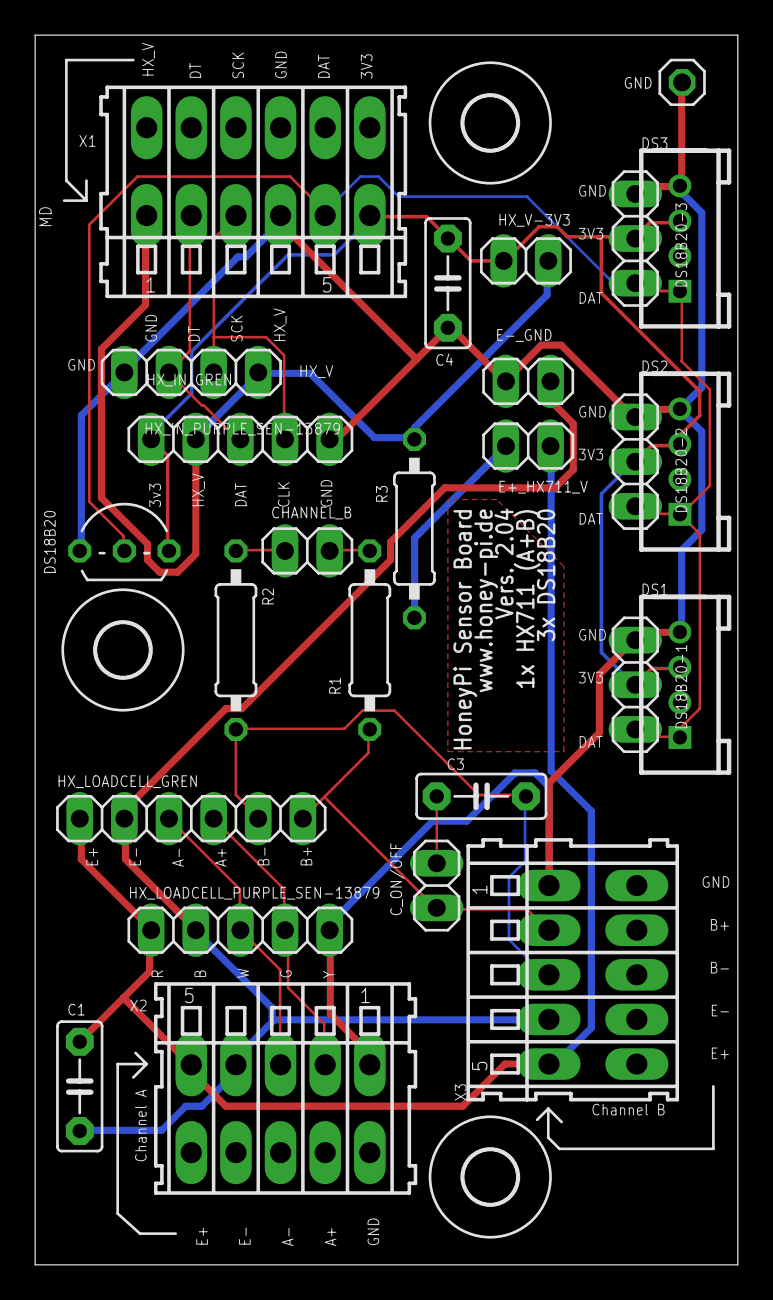
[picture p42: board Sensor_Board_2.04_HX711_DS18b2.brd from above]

Board: 2 copper layers, 40.0 x 70.0 mm, 29 parts (0 on the bottom side), 16 nets.

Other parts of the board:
U$1, U$2, U$5: 3,0

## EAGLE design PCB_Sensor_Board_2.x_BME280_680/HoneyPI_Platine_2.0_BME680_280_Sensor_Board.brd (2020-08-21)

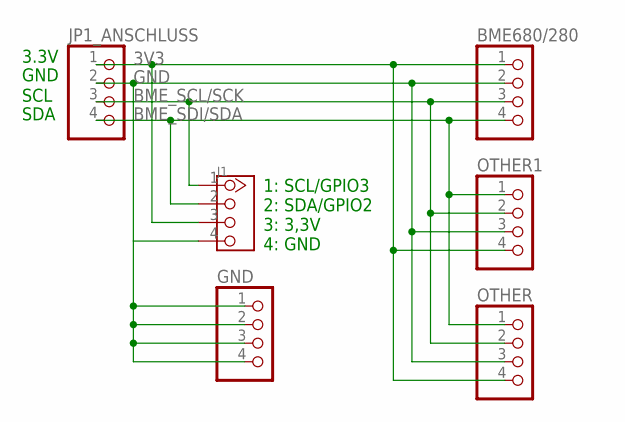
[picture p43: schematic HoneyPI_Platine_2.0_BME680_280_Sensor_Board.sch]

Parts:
BME680/280: PINHD-1X4; 1X04
GND: PINHD-1X4; 1X04
J1: TWIG-4P-2.0-2.0; 4P-2.0
JP1_ANSCHLUSS: PINHD-1X4; 1X04
OTHER, OTHER1: PINHD-1X4; 1X04

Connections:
3V3: BME680/280.1, J1.3, JP1_ANSCHLUSS.1, OTHER.4, OTHER1.4
BME_SCL/SCK: BME680/280.3, J1.1, JP1_ANSCHLUSS.3, OTHER.2, OTHER1.2
BME_SDI/SDA: BME680/280.4, J1.2, JP1_ANSCHLUSS.4, OTHER.1, OTHER1.1
GND: BME680/280.2, GND.1, GND.2, GND.3, GND.4, J1.4, JP1_ANSCHLUSS.2, OTHER.3, OTHER1.3

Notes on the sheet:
GND
SDA
SCL
3.3V
1: SCL/GPIO3 2: SDA/GPIO2 3: 3,3V 4: GND

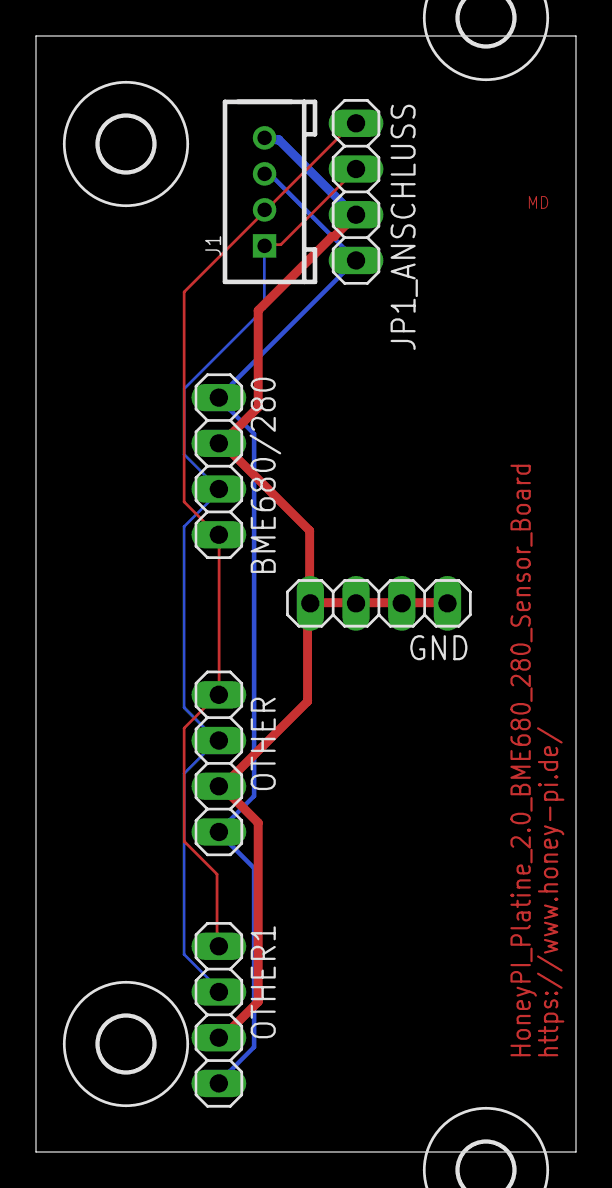
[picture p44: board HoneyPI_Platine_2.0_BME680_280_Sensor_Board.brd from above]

Board: 2 copper layers, 30.0 x 62.0 mm, 10 parts (0 on the bottom side), 4 nets.

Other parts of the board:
U$1, U$2, U$3, U$4: 3,0

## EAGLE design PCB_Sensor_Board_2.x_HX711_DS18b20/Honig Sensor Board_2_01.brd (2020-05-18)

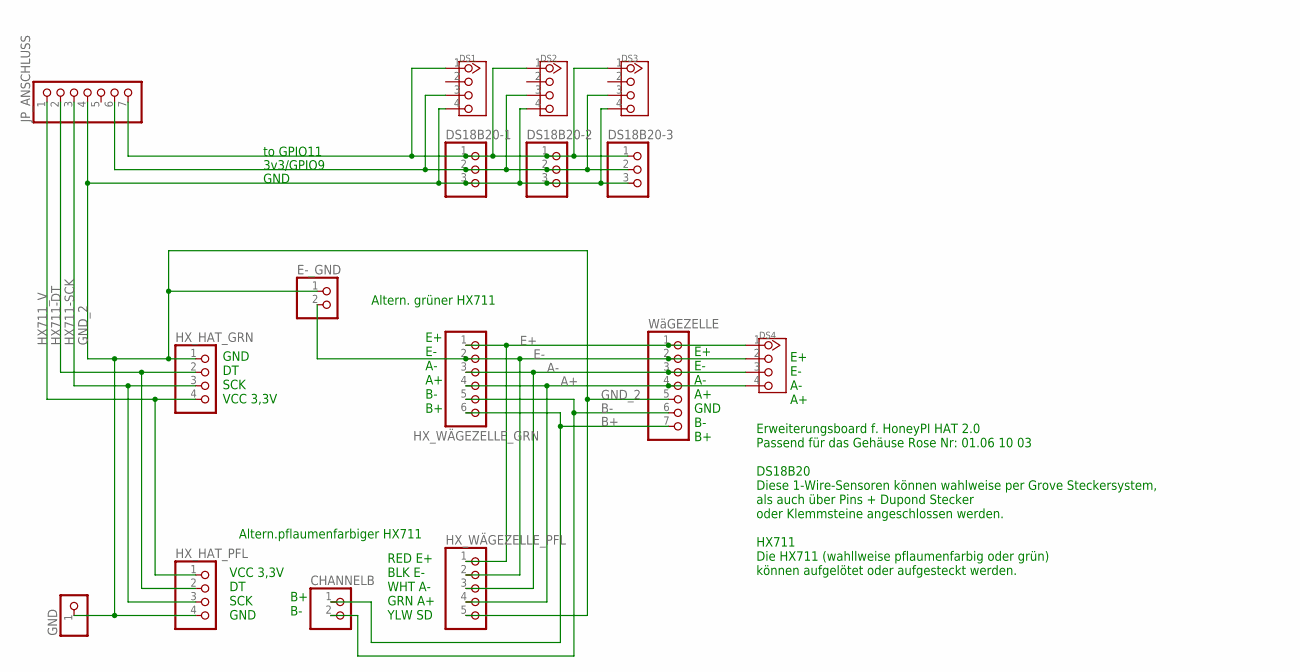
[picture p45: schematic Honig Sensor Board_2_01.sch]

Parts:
CHANNELB: PINHD-1X2; 1X02
DS1, DS2, DS3, DS4: TWIG-4P-2.0-2.0; 4P-2.0
DS18B20-1, DS18B20-2, DS18B20-3: PINHD-1X3; 1X03
E-_GND: PINHD-1X2; 1X02
GND: PINHD-1X1; 1X01
HX_HAT_GRN: PINHD-1X4; 1X04
HX_HAT_PFL: PINHD-1X4; 1X04
HX_WÄGEZELLE_GRN: PINHD-1X6; 1X06
HX_WÄGEZELLE_PFL: PINHD-1X5; 1X05
JP_ANSCHLUSS: PINHD-1X7; 1X07
WäGEZELLE: PINHD-1X7; 1X07

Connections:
3V3: DS1.3, DS2.3, DS3.3, DS18B20-1.2, DS18B20-2.2, DS18B20-3.2, JP_ANSCHLUSS.6
A+: DS4.4, HX_WÄGEZELLE_GRN.4, HX_WÄGEZELLE_PFL.4, WäGEZELLE.4
A-: DS4.3, HX_WÄGEZELLE_GRN.3, HX_WÄGEZELLE_PFL.3, WäGEZELLE.3
B+: CHANNELB.1, HX_WÄGEZELLE_GRN.6, WäGEZELLE.7
B-: CHANNELB.2, HX_WÄGEZELLE_GRN.5, WäGEZELLE.6
DS18B20_DATA_GPIO11_PIN23: DS1.1, DS2.1, DS3.1, DS18B20-1.1, DS18B20-2.1, DS18B20-3.1, JP_ANSCHLUSS.7
E+: DS4.1, HX_WÄGEZELLE_GRN.1, HX_WÄGEZELLE_PFL.1, WäGEZELLE.1
E-: DS4.2, E-_GND.2, HX_WÄGEZELLE_GRN.2, HX_WÄGEZELLE_PFL.2, WäGEZELLE.2
GND_2: DS1.4, DS2.4, DS3.4, DS18B20-1.3, DS18B20-2.3, DS18B20-3.3, E-_GND.1, GND.1, HX_HAT_GRN.1, HX_HAT_PFL.4, HX_WÄGEZELLE_PFL.5, JP_ANSCHLUSS.4, WäGEZELLE.5
HX711-DT: HX_HAT_GRN.2, HX_HAT_PFL.2, JP_ANSCHLUSS.2
HX711-SCK: HX_HAT_GRN.3, HX_HAT_PFL.3, JP_ANSCHLUSS.3
HX711_V: HX_HAT_GRN.4, HX_HAT_PFL.1, JP_ANSCHLUSS.1

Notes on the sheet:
3v3/GPIO9
VCC 3,3V DT SCK GND
GND DT SCK VCC 3,3V
GND
to GPIO11
Erweiterungsboard f. HoneyPI HAT 2.0 Passend für das Gehäuse Rose Nr: 01.06 10 03 DS18B20 Diese 1-Wire-Sensoren können wahlweise per Grove Steckersystem, als auch über Pins + Dupond Stecker oder Klemmsteine angeschlossen werden. HX711 Die HX711 (wahllweise pflaumenfarbig oder grün) können aufgelöte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
E+ E- A- A+ B- B+
RED E+ BLK E- WHT A- GRN A+ YLW SD
B+ B-
Altern.pflaumenfarbiger HX711
Altern. grüner HX711
E+ E- A- A+ GND B- B+
E+ E- A- A+

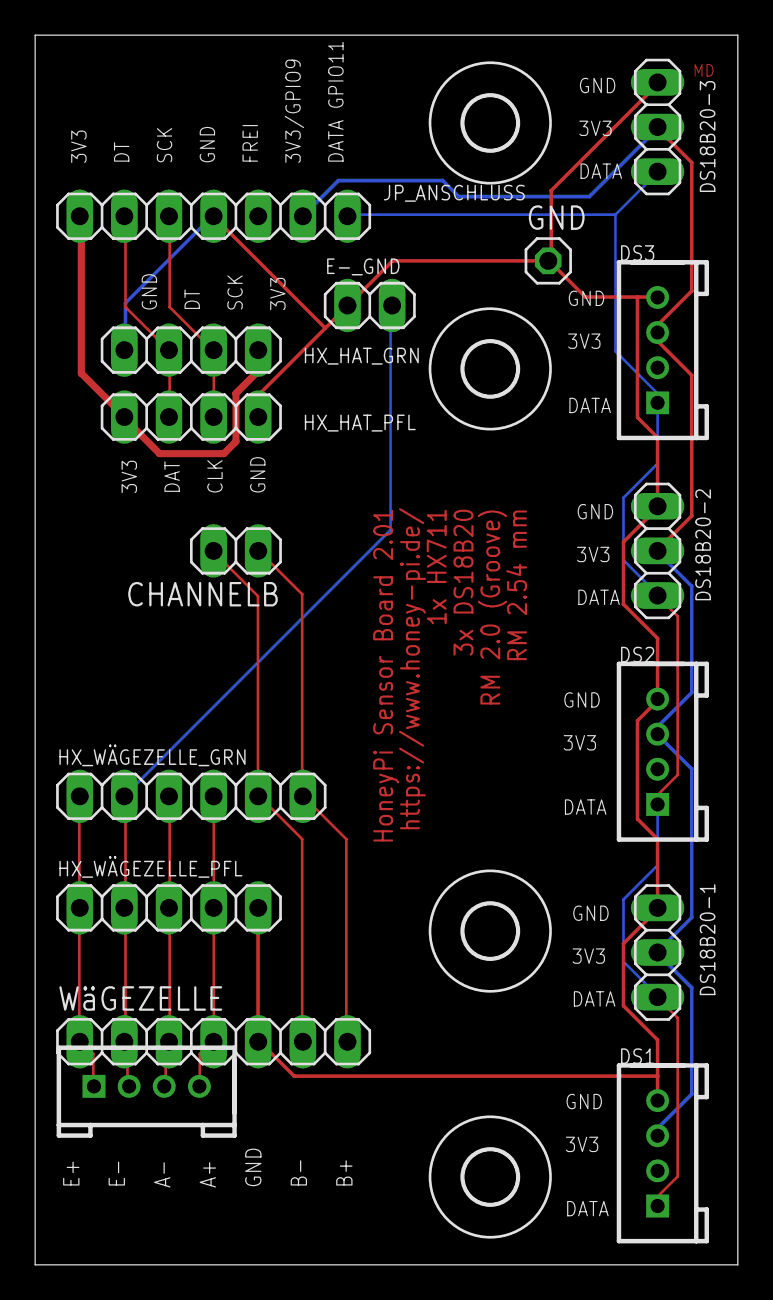
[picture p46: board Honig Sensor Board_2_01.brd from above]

Board: 2 copper layers, 40.0 x 70.0 mm, 20 parts (0 on the bottom side), 12 nets.

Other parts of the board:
U$1, U$2, U$3, U$4: 3,0

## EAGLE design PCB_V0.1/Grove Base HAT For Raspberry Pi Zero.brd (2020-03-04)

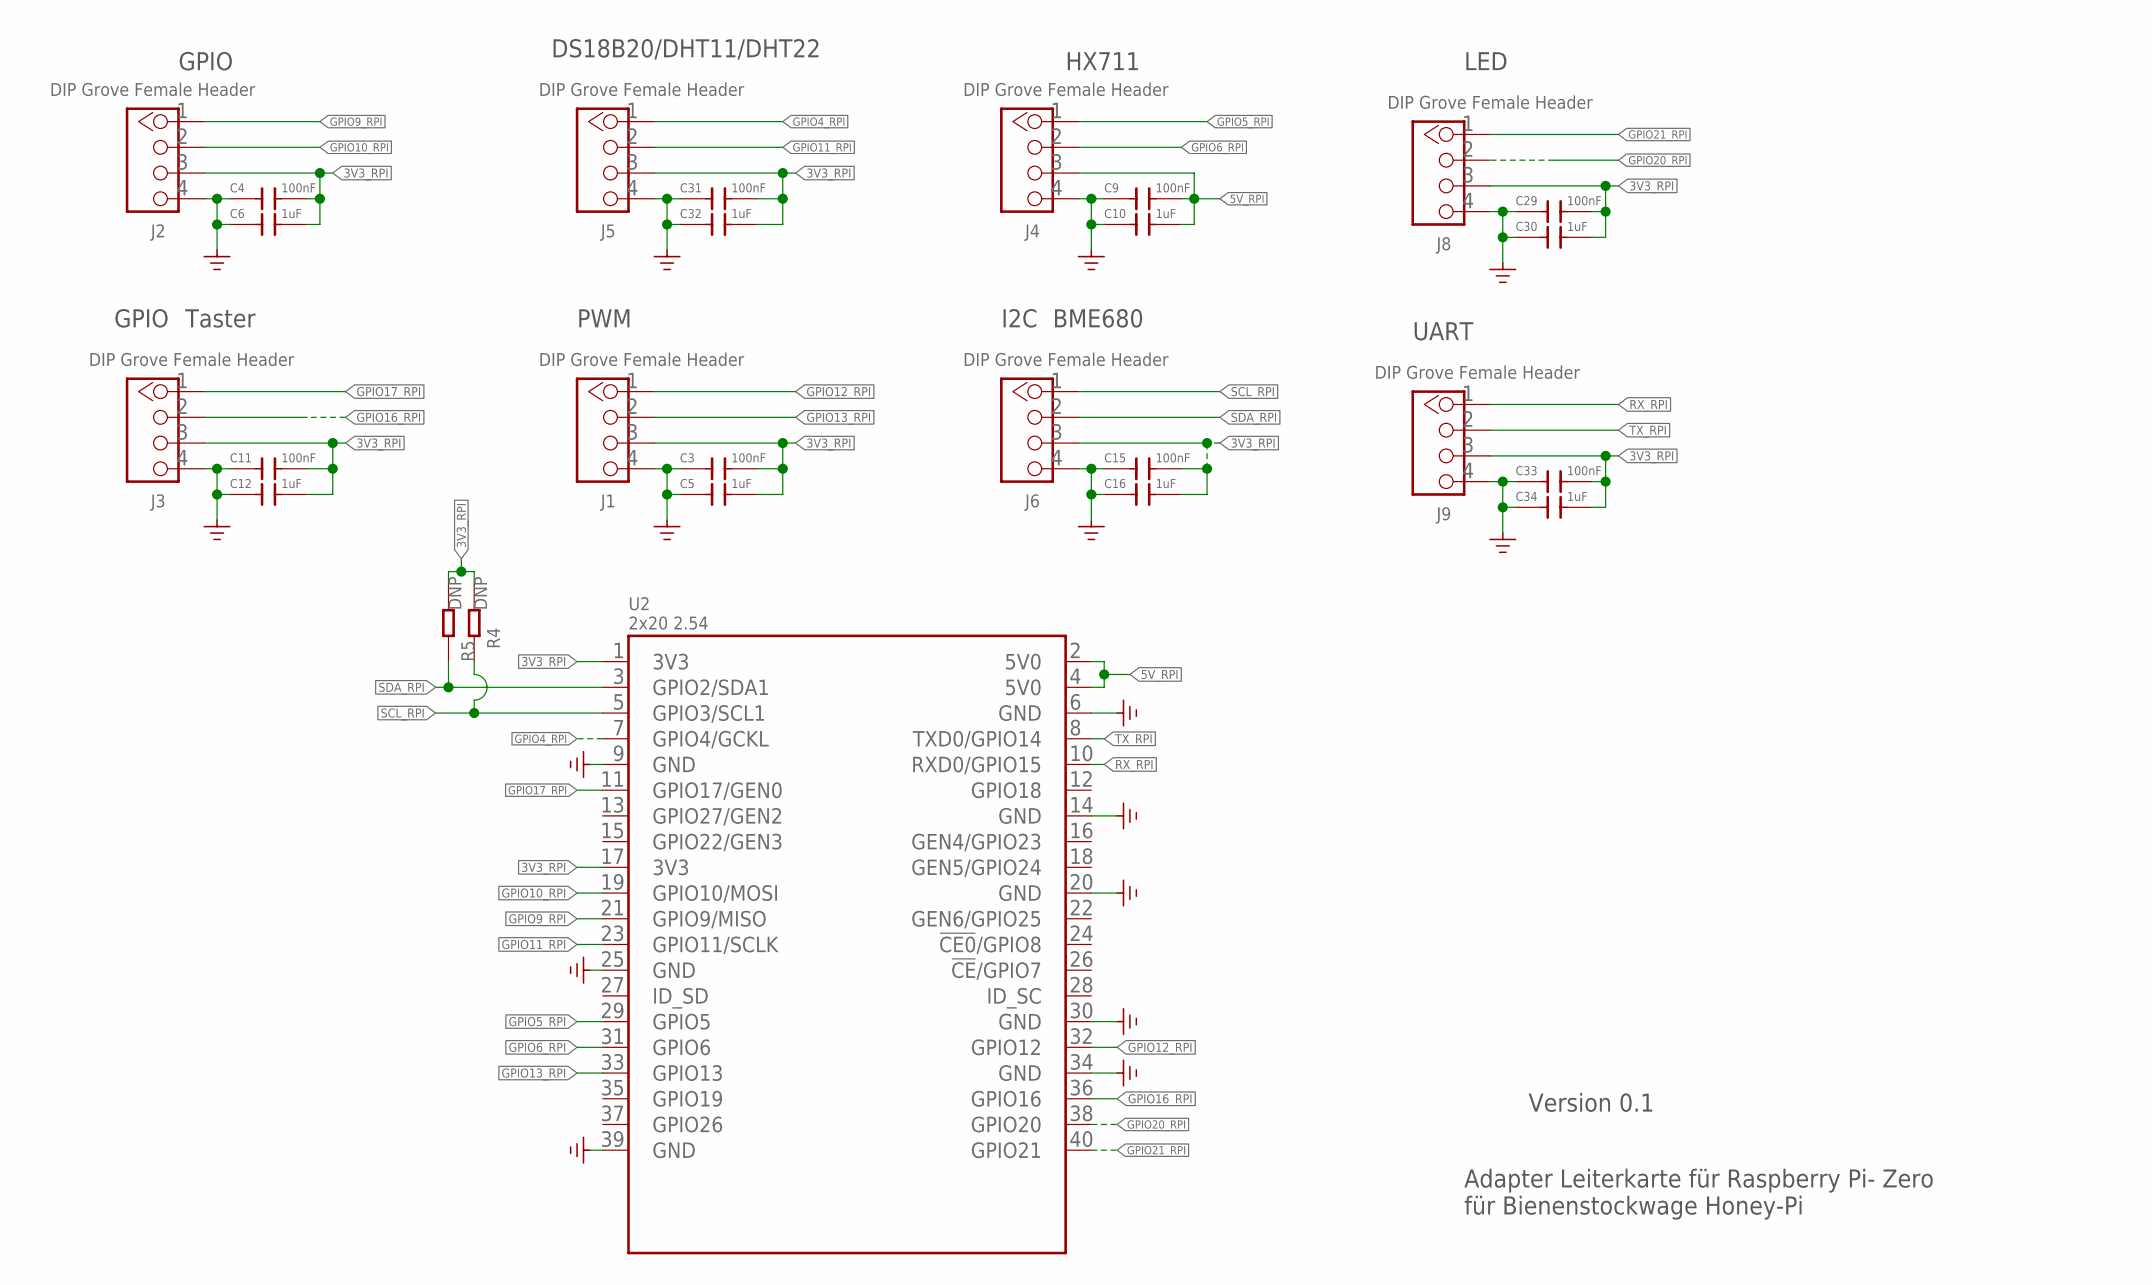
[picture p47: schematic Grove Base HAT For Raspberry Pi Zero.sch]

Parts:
C3, C4, C9, C11, C15, C29, C31, C33: 100nF; C0603
C5, C6, C10, C12, C16, C30, C32, C34: 1uF; C0603
J1, J2, J3, J4, J5, J6, J8, J9: DIP Grove Female Header; HW4-2.0
R4, R5: DNP; R0603
U2: 2x20 2.54; RASPBERRYPI_BASTELSTUBE_V13_RASPI_BOARD_B+_FULL

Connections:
3V3_RPI: C3.2, C4.2, C5.2, C6.2, C11.2, C12.2, C15.2, C16.2, C29.2, C30.2, C31.2, C32.2, C33.2, C34.2, J1.3, J2.3, J3.3, J5.3, J6.3, J8.3, J9.3, R4.2, R5.2, U2.1 (3V3), U2.17 (3V3)
5V_RPI: C9.2, C10.2, J4.3, U2.2 (5V0), U2.4 (5V0)
GND: C3.1, C4.1, C5.1, C6.1, C9.1, C10.1, C11.1, C12.1, C15.1, C16.1, C29.1, C30.1, C31.1, C32.1, C33.1, C34.1, J1.4, J2.4, J3.4, J4.4, J5.4, J6.4, J8.4, J9.4, U2.6 (GND), U2.9 (GND), U2.14 (GND), U2.20 (GND), U2.25 (GND), U2.30 (GND), U2.34 (GND), U2.39 (GND)
GPIO4_RPI: J5.1, U2.7 (GPIO4/GCKL)
GPIO5_RPI: J4.1, U2.29 (GPIO5)
GPIO6_RPI: J4.2, U2.31 (GPIO6)
GPIO9_RPI: J2.1, U2.21 (GPIO9/MISO)
GPIO10_RPI: J2.2, U2.19 (GPIO10/MOSI)
GPIO11_RPI: J5.2, U2.23 (GPIO11/SCLK)
GPIO12_RPI: J1.1, U2.32 (GPIO12)
GPIO13_RPI: J1.2, U2.33 (GPIO13)
GPIO16_RPI: J3.2, U2.36 (GPIO16)
GPIO17_RPI: J3.1, U2.11 (GPIO17/GEN0)
GPIO20_RPI: J8.2, U2.38 (GPIO20)
GPIO21_RPI: J8.1, U2.40 (GPIO21)
RX_RPI: J9.1, U2.10 (RXD0/GPIO15)
SCL_RPI: J6.1, R4.1, U2.5 (GPIO3/SCL1)
SDA_RPI: J6.2, R5.1, U2.3 (GPIO2/SDA1)
TX_RPI: J9.2, U2.8 (TXD0/GPIO14)

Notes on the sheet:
PWM
GPIO
UART
I2C
Version 0.1
Adapter Leiterkarte für Raspberry Pi- Zero für Bienenstockwage Honey-Pi
HX711
Taster
LED
DS18B20/DHT11/DHT22
BME680

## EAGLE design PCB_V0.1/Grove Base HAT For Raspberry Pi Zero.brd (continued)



Board: 2 copper layers, 65.0 x 30.0 mm, 27 parts (18 on the bottom side), 19 nets.

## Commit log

2020-03-04 Initial commit of Version v0.1
    [Grove Base HAT For Raspberry Pi Zero.brd, Grove Base HAT For Raspberry Pi Zero.sch]
2020-05-06 Beta 2.0:
    For purchasing and testing
    [HoneyPI_Platine 2.0.brd, HoneyPI_Platine 2.0.sch, Honig Sensor Board_2.brd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]
2020-05-18 Version added
    [Honig Sensor Board_2.brd, Honig Sensor Board_2.sch]
2020-05-18 Correction 2.0 -> 2.01
    Correction of the pin description
    [Honig Sensor Board_2_01.brd, Honig Sensor Board_2_01.sch]
2020-05-18 Correction 2.0 -> 2.01
    Moved: 2.0 to OLD
    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
    [Honig Sensor Board_2.brd, Honig Sensor Board_2.sch]
2020-06-10 New version
    [Honig Sensor Board_2_01.brd, Honig Sensor Board_2_01.sch, Sensor_Board_2.01_HX711_DS18b2.brd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]
2020-06-10 Create HoneyPI_Platine 2.01 Sensor Plan.pdf
2020-06-10 add_ 1x DS18B20 TO-92
    [Sensor_Board_2.01_HX711_DS18b2.brd, Sensor_Board_2.01_HX711_DS18b2.sch]
2020-06-10 only small changes :-)
    [HoneyPI_Platine 2.0.sch, HoneyPI_Platine 2.01.brd, HoneyPI_Platine 2.01.sch]
2020-06-10 New circuit diagram
2020-06-21 alpha status!
    [HoneyPI_Platine TimerBoard 2.0.brd, HoneyPI_Platine TimerBoard 2.0.sch]
2020-06-30 3rd i²C interface
    [HoneyPI_Platine_2.0_BME680_280_Sensor_Board.brd, HoneyPI_Platine_2.0_BME680_280_Sensor_Board.sch]
2020-06-30 2x Polyfuse
    The circuit has been extended by 2 optional polyfuses or similar. The fuse size has been accepted and not yet verified.
    Please note: The operator of the board must ensure safe operation. Accordingly, a fuse must be installed in accordance with the regulations.
    [HoneyPI_Platine_2.01.brd, HoneyPI_Platine_2.01.sch]
2020-06-30 Switch for timer on/off
    switch for switching from time control to standard operation inserted
2020-08-21 Updates, updates....
    [HoneyPI_Platine TimerBoard 2.0.brd, HoneyPI_Platine TimerBoard 2.0.sch, HoneyPI_Platine TimerBoard 2.00a.brd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]
2020-08-21 Updates, updates...
    [HoneyPI_Platine_2.0_BME680_280_Sensor_Board.brd, HoneyPI_Platine_2.0_BME680_280_Sensor_Board.sch]
2020-08-21 Filenames corrected
    [HoneyPI_I2C_Extenter.brd, HoneyPI_I2C_Extenter.sch]
2020-08-21 Twisted pairs cable info
    [HoneyPI_I2C_Extenter.brd]
2020-11-16 Gerber file produced with new CAM file and some small manual changes
2020-11-16 Gerber update
    [PCB_Sensor_Board_2.x_BME280_680_ATH10_HDC1080.brd, PCB_Sensor_Board_2.x_BME280_680_ATH10_HDC1080.sch]
2020-11-16 Gerberfiles update
2020-12-19 _ instead of space in the file name of the gerber file
2021-01-05 New releases
    Fix BME680_GROVE Pinout on the main board
    Some corrections on the sensor board
    [HoneyPI_Platine_2.01.1.brd, HoneyPI_Platine_2.01.1.sch, HoneyPI_Platine_2.02.brd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]
2021-01-11 Label corection (3V3 <-> DAT)
    [Sensor_Board_2.03_HX711_DS18b2.brd, Sensor_Board_2.03_HX711_DS18b2.sch]
2021-02-18 cleaning: old files -> \old\
    [Sensor_Board_2.01_HX711_DS18b2.brd, Sensor_Board_2.01_HX711_DS18b2.sch, Sensor_Board_2.02_HX711_DS18b2.brd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]
2021-02-20 Some printed parts
    [Sensor_housing.stl, Sensor_housing_cover.stl, Sensor_housing_cover_countersunk_head.stl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]
2021-03-27 Modem beta
    [config.txt]
2021-05-04 updated Modem, added installer
    [config.txt]
2021-12-19 Ver. 2.04
    I2C address overview
    Sensor SHT20
2022-04-13 Update to 2.04
    [Sensor_Board_2.03_HX711_DS18b2.brd, Sensor_Board_2.03_HX711_DS18b2.sch, Sensor_Board_2.04_HX711_DS18b2.brd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]
2022-08-13 fix bme680_grove pinout
    [HoneyPI_Platine_2.02.brd, HoneyPI_Platine_2.02.sch, HoneyPI_Platine_2.021.brd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]
2022-08-15 Upload gerber files
2023-04-10 Pictures from the alpha pcb
2023-11-28 CH8_CH_8.5
    To fit more than on HX711 with slide different measure of the pins CH8 and CH_8.5
    [Sensor_Board_2.04_HX711_DS18b2.brd, Sensor_Board_2.04_HX711_DS18b2.sch]
